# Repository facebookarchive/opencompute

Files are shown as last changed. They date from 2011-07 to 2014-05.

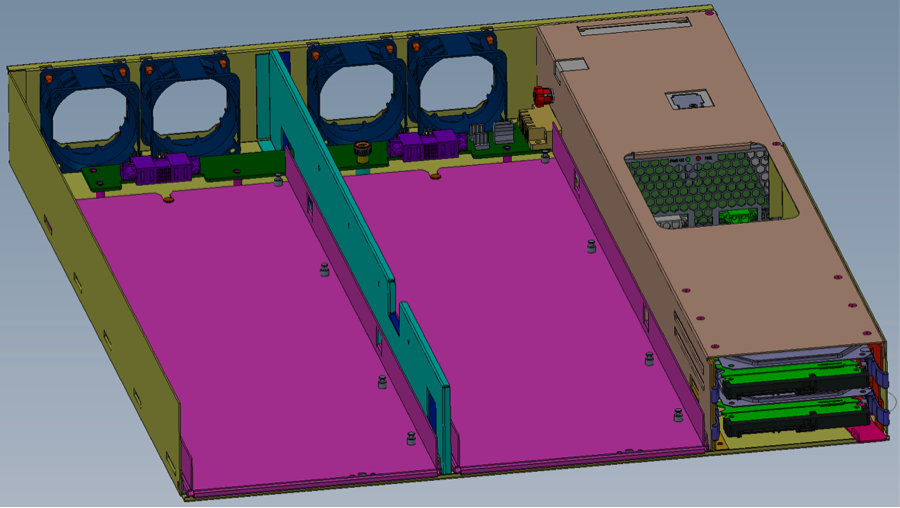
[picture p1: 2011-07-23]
Intel_server_V2/images/ocp_chassis.png

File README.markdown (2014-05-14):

Archived Repo
=============
**This is an archived project: please do not file issues or pull-requests against this repo. All Open Compute specifications are available directly from http://www.opencompute.org/projects/**

# Open Compute Project

Welcome to our beta Git repository. In it you will find specs in multimarkdown for our Intel and AMD V2 motherboard Incubation Projects, as well as a preliminary spec for the Open Rack Incubation Project and a charter for the Open Hardware Management Incubation Project. Mechanical CAD files will be forthcoming. We also have a small project, called Alpha, for converting multimarkdown specs into multi-page pdfs. It is non-functional until the instructions for installing all the latex tools are documented.

One thing to note: the OCP logos for HTML and PDF generation are in /alpha/images. You will need to manually symlink the images in there to a particular project's images folder. The gitmmd2pdf.py script will do this for you, but this script won't generate nice output or compile unless you have all the latex tools installed.

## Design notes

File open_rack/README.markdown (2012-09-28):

This is the Open Rack Incubation project.

Specs and some CAD files are available in the /spec directory. However, the Open Rack 1.0 STEP file can be downloaded from the OCP site at:

http://opencompute.org/wp/wp-content/uploads/2012/09/06-00050_SINGLET_RACK_WITH_BUS_BAR_OPEN_RACK_OCP_REV1_0.rar

You can find the charter in /charter.

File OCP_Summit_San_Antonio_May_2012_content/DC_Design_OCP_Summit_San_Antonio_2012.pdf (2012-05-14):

# Operational Performance and Efficiencies

# Direct Evaporative Cooling/Humidification Systems Comparison

## dan lee, p.e., leed bd+c facebook mechanical engineer, datacenter design

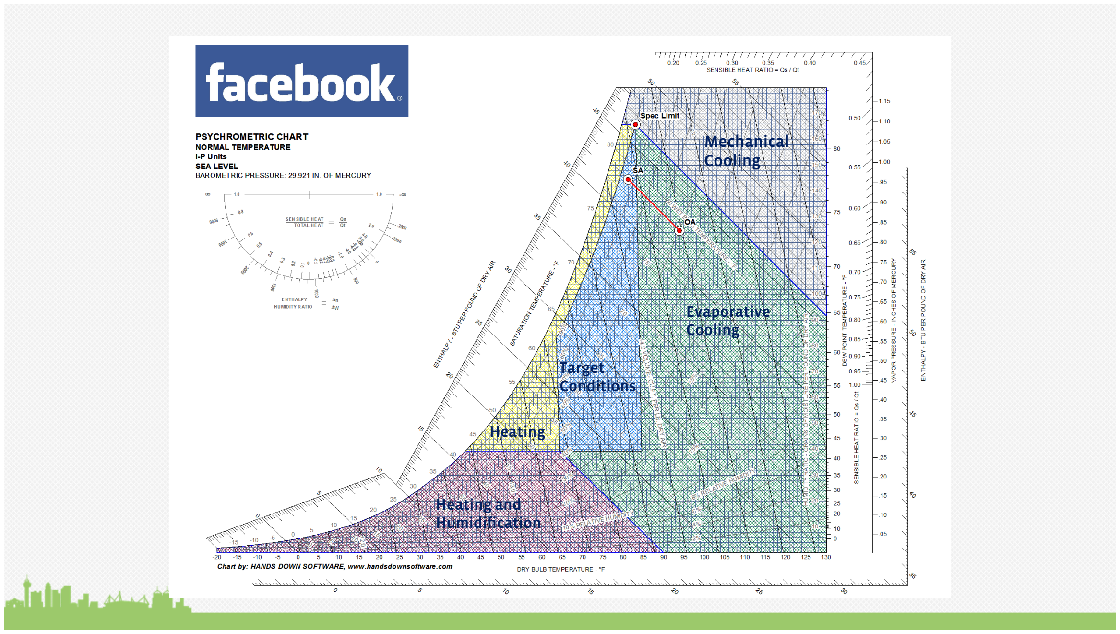
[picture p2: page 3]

Mechanical
Cooling

Evaporative
Cooling

Heating and
Humidification

Heating

Target
Conditions

# Evaporative Cooling

## Scientific Facts: ▪Water evaporates and cools (“free cooling”) ▪Water evaporates on water surface ▪Water evaporation rate is proportional to surface area available

# Atomizing Type Humidifiers

▪Humidifiers break up water into mist, micron sized droplets,

## for rapid moisture absorption ▪There are 2 methods of atomizing water into droplets 1. Pressure Atomizing: High pressure and shear force at humidifier nozzles break water up into a fine mist, used at Facebook 2. Ultrasonic: Ultrasonic vibration breaks water up into a fine mist, not used at Facebook

# Atomizing Type Humidifiers

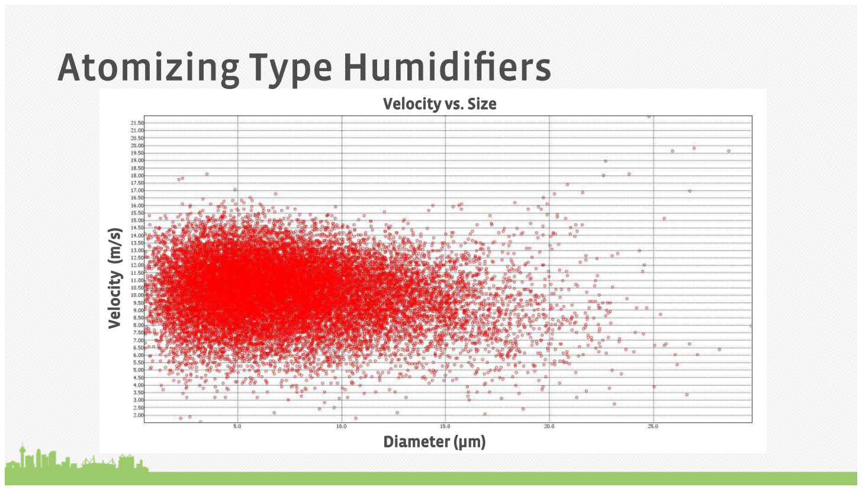
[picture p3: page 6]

Velocity vs. Size

Diameter (µm)

Velocity (m/s)

Misting nozzle with impingement pin

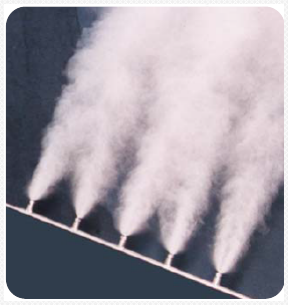
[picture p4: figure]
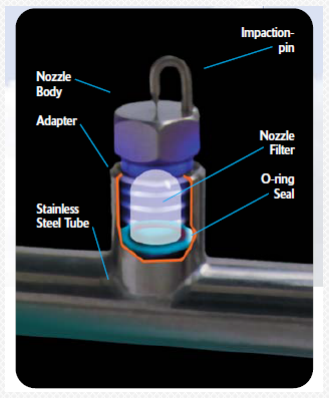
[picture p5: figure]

Misting nozzles with plunger

# Atomizing Type Misting Nozzles

# Typical Misting System Installation

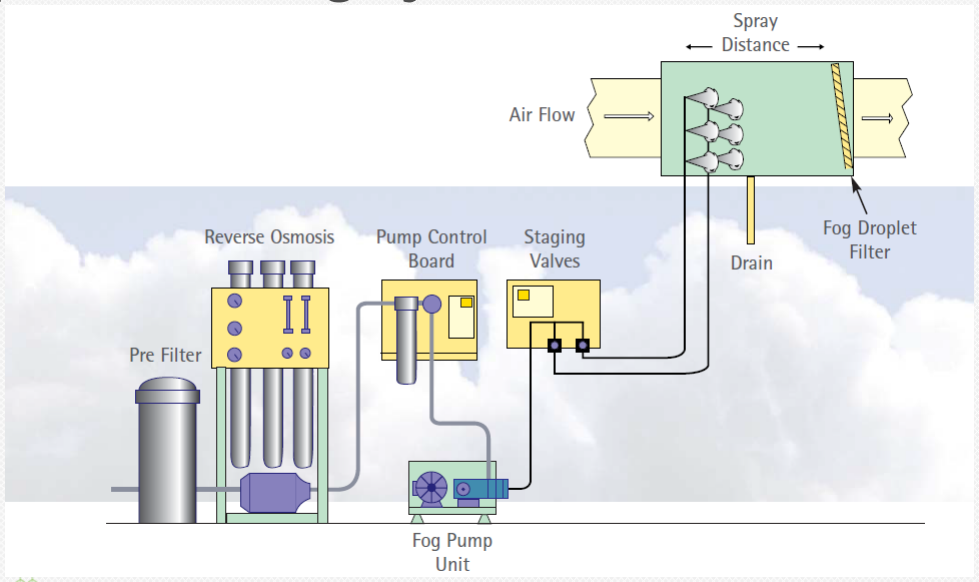
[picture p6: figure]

# Typical Misting Array

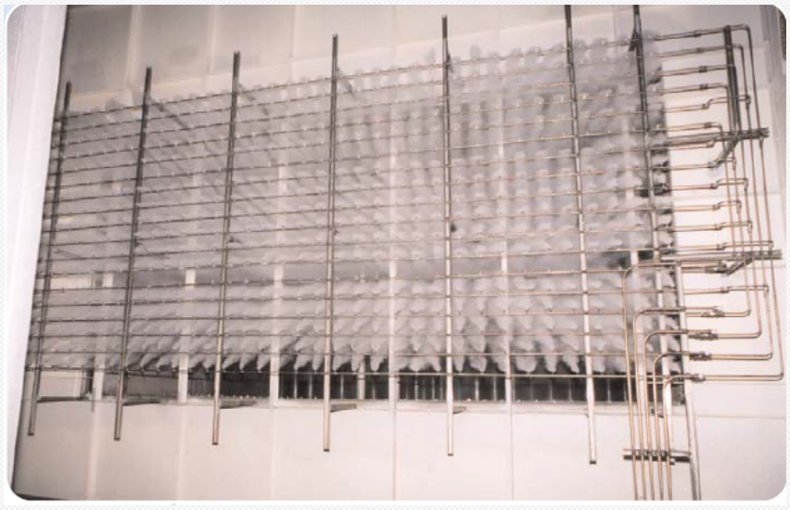
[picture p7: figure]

### - Pros:

1. Good capacity control
2. Not consumable
3. Almost no pressure drop at misting nozzle array

### - Cons:

1. Need RO water => CAPEX/OPEX and foot print for RO Plant
2. RO blow-downs consumes more water than media
3. Types of pressure atomizing heads have impingement pins at the nozzle which need precise tuning to maintain optimal atomizing efficiency. Others have moving parts (plungers/check valves ) in the nozzles that may fail
4. Misting nozzle orifices are very small => Subject to clogging
5. Components on high pressure side (1000psig ) are made of stainless steel => CAPEX
6. Need space to provide the absorption distance
7. Good percentage (15-20%) of water being sprayed drops out of air stream, need mist eliminator and water recycling/polishing system
8. Mist eliminator cause pressure drop in the system => Money to buy and energy to operate

# Atomizing Type Misting Systems

# Typical Media System Installation

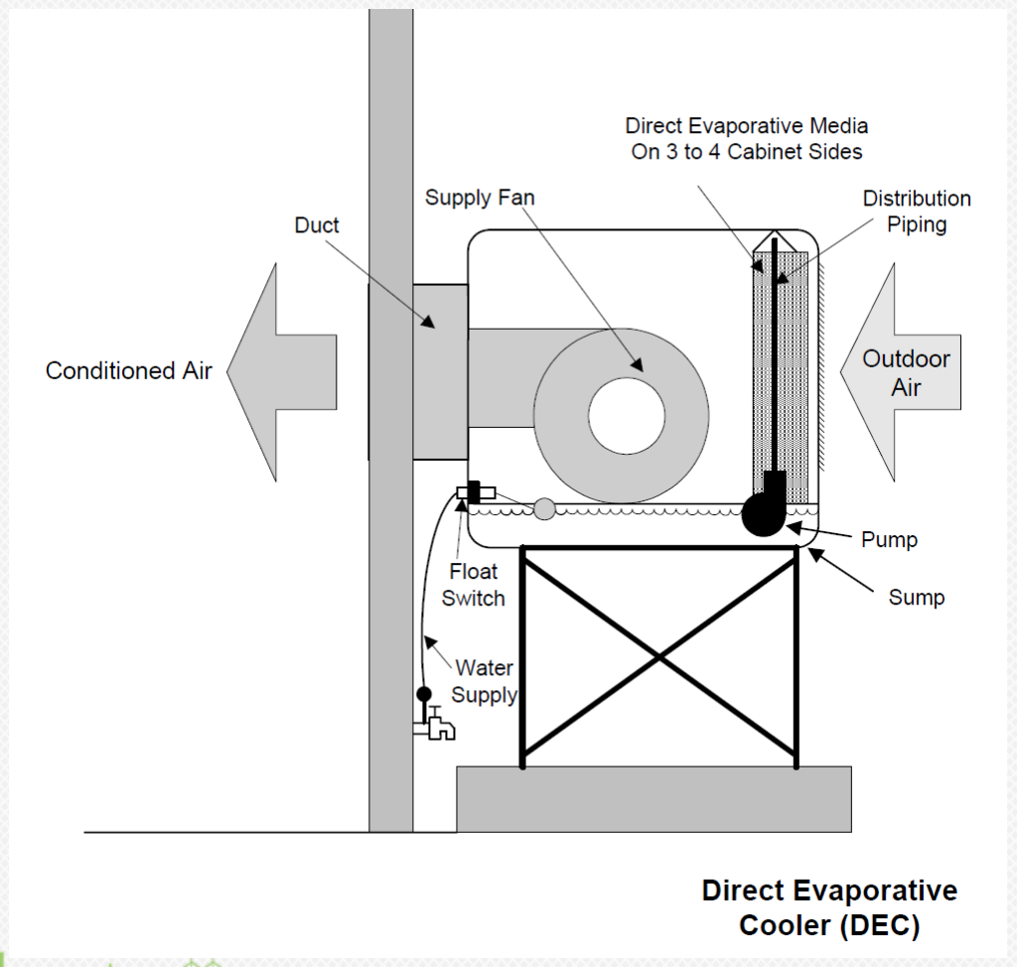
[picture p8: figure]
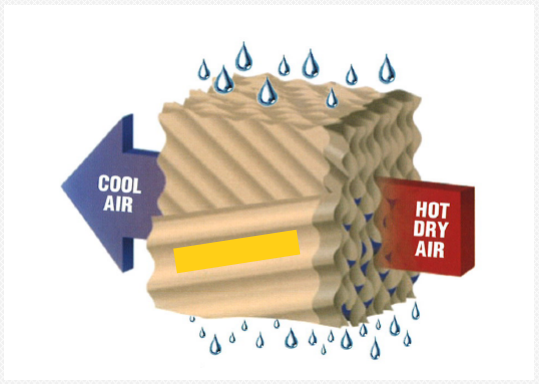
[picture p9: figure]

Fiberglass media in humidifier sections provide extended wet surface for adequate water evaporation to humidify
- Pros:
1. No RO system required => Save cost and foot print for RO system
2. No misting nozzle orifices to potentially clog up
3. No impingement pins to adjust or moving parts in misting nozzles
4. Save space => Absorption distance 8-inches vs. 6-feet
5. System operating pressure is low, no stainless steel components required=> low equipment cost and installation cost
6. Lowest TCO
7. Better Particles removal capability
- Cons:
1. Poor capacity controls: Finite number of steps available
2. System lag: Time to wet ( up cycle ) and time to dry ( down cycle )
3. Media has limited life span, 3-5 years normal use, but could be shorten due to rapid wetting and drying or improper system blow-downs
4. Pressure drop across media

# Direct Evaporative Media Type System

DRY | WET
Velocity (fpm) | Pressure Drop ("WC) | Velocity (fpm) | Pressure Drop ("WC)
3294 | 3.340 | 3311 | 3.340
3055 | 2.920 | 2931 | 2.700
2776 | 2.430 | 2750 | 2.380
2535 | 2.040 | 2479 | 1.950
2129 | 1.450 | 2282 | 1.660
1538 | 0.820 | 2061 | 1.360
1168 | 0.480 | 1822 | 1.050
1002 | 0.400 | 1669 | 0.958
634 | 0.190 | 1281 | 0.609
528 | 0.142 | 733 | 0.202
495 | 0.134 | 538 | 0.152
441 | 0.115 | 507 | 0.135
388 | 0.093 | 462 | 0.115
327 | 0.072 | 417 | 0.103
269 | 0.057 | 356 | 0.082
243 | 0.050 | 299 | 0.064
191 | 0.036 | 276 | 0.056
152 | 0.027 | 221 | 0.040
78 | 0.012 | 119 | 0.017
Mist Eliminator

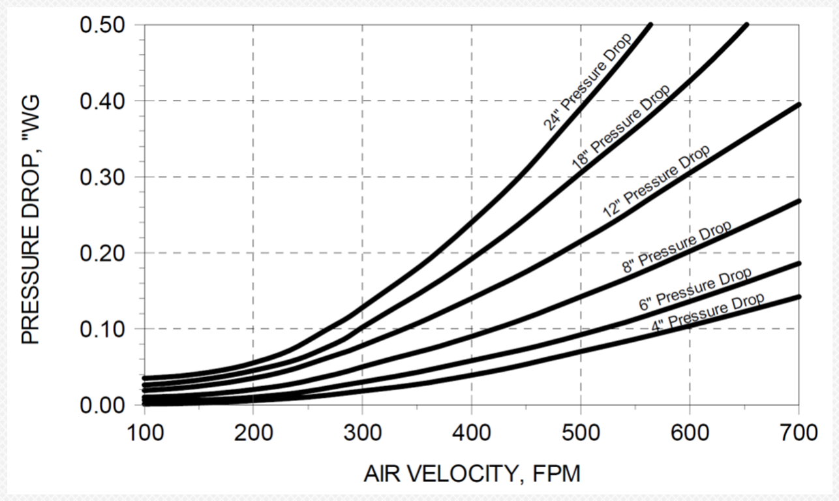
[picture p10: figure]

Direct Evaporative Media

# Air Pressure Drop Comparison

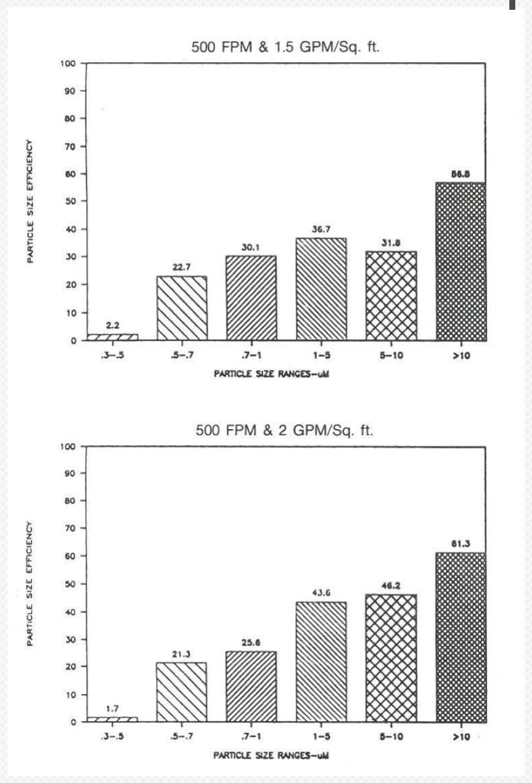
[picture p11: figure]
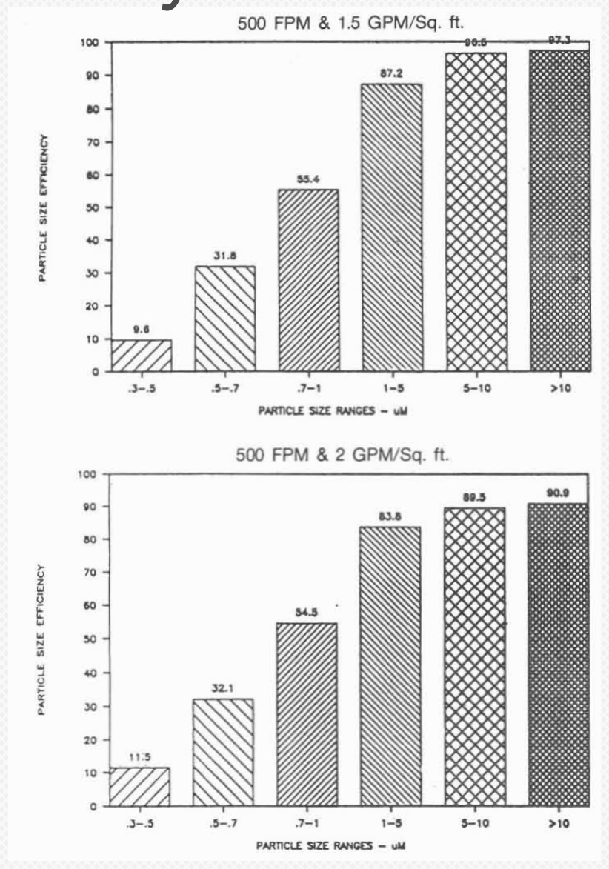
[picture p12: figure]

6” Deep Media | 12” Deep Media

## Particulates Removal Capability of Media System

15

| Misting | Media | Remarks
Reverse Osmosis System | Required | Not required
Reverse Osmosis Plant Space | Required | Not required
Piping material | Stainless | CPVC
Absorption Distance | 6-10ft | 8-12 inches
Misting Nozzle Adjustment | Required | Not required
Misting Nozzles clogging | Yes | No
Capacity Control | Good | Acceptable
Water Consumption | Slightly higher | Slightly lower | RO and Softener blow-down
System Consumable | No | Yes | Media need Replacement
Particles Removal Capability | Less favorable | More Favorable
Pressure Drop | equal | equal | Media vs. Mist eliminator
CAPEX | High | Low | At least a 15% savings
OPEX | Slightly Higher | Slightly lower | RO up-keep vs. Media replacement RO Blow-down vs. Over spraying
Overall | Less Favorable | More Favorable

# Attributes Comparison

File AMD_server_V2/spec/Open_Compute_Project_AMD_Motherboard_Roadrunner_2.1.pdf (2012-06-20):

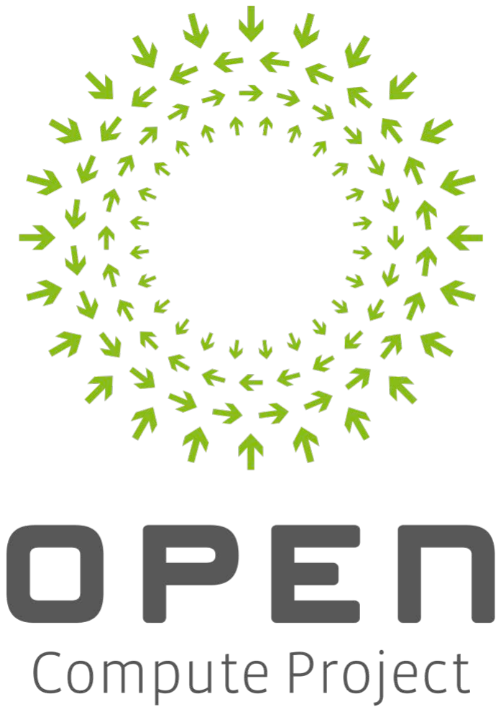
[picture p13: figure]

# AMD Motherboard Hardware v2.1

Authors: Bob Ogrey, Eugene Chung, Otto Joe

2 | April 15, 2012
1 | Revision History
2 | Scope This document defines the technical specifications for the general purpose AMD motherboard that will be used in financial services Open Compute Project servers.
Date | Revision | Description
May 2012 | 1.0 | Initial Release to OCP
June 2012 | 1.1 | Changed Add-in Management Controller Connector, Changed Mezzanine connector, Modified Block Diagram to support BCM5720, Added in EMC and UL safety requirements, added Power Supply Information, Integrated partner feedback

Open Compute Project AMD Motherboard Hardware v2.1

http://opencompute.org | 3
3 | Contents 1 Revision History | 2 2 Scope | 2 3 Contents | 3 4 Overview | 5 4.1 License | 5 4.2 CAD
Models | 6
| 5 Product Descriptions

and

Requirements | 6
| 6 Motherboard
Features | 7
| 6.1 Block

Diagram

for

Base

Design

Implementation | 9
| 6.2 Placement

and

Form

Factor | 9
| 6.3 CPU

and

Memory | 10
| 6.4 Northbridge

PCIe

Usage | 13
| 6.5 Southbridge/Peripheral
Bus Controller | 13
| 7 Leveraged
Design | 13
| 7.1 HPC

Server

in

1U

Chassis | 14
| 7.2 General

Purpose

Motherboard

in

2U

Chassis | 16
| 7.3 Storage

Server Motherboard

in

3U

Chassis | 18
| 8 Chassis Information | 20 8.1 Supported
Configurations | 20
| 8.2 Front

Panel

Switches

and

Indicators | 20
| 8.3 Heat
Sinks | 20
| 9 BIOS | 21 9.1 BIOS
Chip | 21
| 9.2 BIOS
Socket | 21
| 9.3 BIOS

Source

Code | 21
| 9.4 BIOS

Power

Optimization

Features | 21
| 9.5 BIOS

Setup

Menu | 21
| 9.6 Console
Redirect | 22
| 9.7 PXE Boot | 22 9.8 Other
Boot
Options | 22
| 9.9 Remote

BIOS

Update | 22

9.10 Event

Log | 23
10 System
Management | 24
10.1 Requirements | 24
10.2 Management
Port | 25
10.3 Temperature
Sensors | 25
10.4 Fan
Connections | 25
11 Power
System | 25
11.1 Power
Supply | 25
11.2 Power

Connector

Pin-‐out | 26
11.3 Support

for

Open

Compute

Infrastructure | 26
11.4 Power

Budget

for

Open

Platform

Board

Configurations | 27
11.5 VRM
Specifications | 28
11.6 Power
Sequencing | 28
11.7 Power

Optimized

Hardware

Features | 28
12 I/O
System | 29
12.1 PCI-‐Express
Slots | 29
12.2 PCIe

Mezzanine

Card | 29
12.3 IMC

Management

Connector | 30
12.4 Network | 33
12.5 USB
Interfaces | 33
12.6 SATA | 33
12.7 Debug
Header | 33
13 Environmental
Requirements | 34
13.1 Regulatory
Compliance | 34
13.2 Vibration

and

Shock | 34
14 Prescribed
Materials | 35
14.1 Disallowed
Components | 35
14.2 Capacitors

and

Inductors | 35
15 Operating

System

Support | 36
16 Adherence

to

AMD

Motherboard

Design | 36

4 | Overview This document describes the "AMD Financial Services Open Platform and System Solutions," hereafter referred to as the Open Platform board. The AMD Financial Services Open Platform is a G34 motherboard that is optimized for cost and power, and designed to fit into a 1U, 1.5U, 2U, 3U or taller chassis to support different hard drive configurations. The chassis will house this 16" by 16.7" board and come in different U-heights depending on the use case. This system is intended as a low power offering with a feature set tailored to meet the needs of large data center operators and cloud computing service providers. The AMD Financial Services Open Platform is intended to provide a universal, highly re- useable common motherboard that targets 70% to 80% of enterprise infrastructure of Wall Street Council members. Compatibility and deploy-ability are chief design objectives and boards should fit into both the Open Compute/Facebook datacenter infrastructure as well as traditional Enterprise 19" rack enclosures. This means the solution will provide a flexible power delivery system that supports both Facebook Open Compute & Traditional Enterprise Datacenter high-efficiency power supplies. Like previous Open Compute projects, this motherboard is power-optimized and barebones, designed to provide the lowest capital and operating costs. The Open Platform board enables customer driven (versus OEM driven) hardware core features and requirements and will drive an open standards approach that should generate volume and competitive pricing.
4.1 | License As of April 7, 2011, the following persons or entities have made this Specification available under the Open Web Foundation Final Specification Agreement (OWFa 1.0), which is available at http://www.openwebfoundation.org/legal/the-owf-1-0-agreements/owfa-1-0 Facebook, Inc. You can review the signed copies of the Open Web Foundation Agreement Version 1.0 for this Specification at http://opencompute.org/licensing/, which may also include additional parties to those listed above. Your use of this Specification may be subject to other third party rights. THIS SPECIFICATION IS PROVIDED "AS IS." The contributors expressly disclaim any warranties (express, implied, or otherwise), including implied warranties of merchantability, non- infringement, fitness for a particular purpose, or title, related to the Specification. The entire risk as to implementing or otherwise using the Specification is assumed by the Specification implementer and user. IN NO EVENT WILL ANY PARTY BE LIABLE TO ANY OTHER PARTY FOR LOST PROFITS OR ANY FORM OF INDIRECT, SPECIAL, INCIDENTAL, OR CONSEQUENTIAL DAMAGES OF ANY CHARACTER FROM ANY CAUSES OF ACTION OF ANY KIND WITH RESPECT TO THIS SPECIFICATION OR ITS GOVERNING AGREEMENT, WHETHER BASED ON BREACH OF CONTRACT, TORT (INCLUDING NEGLIGENCE), OR OTHERWISE, AND WHETHER OR NOT THE OTHER PARTY HAS BEEN ADVISED OF THE POSSIBILITY OF SUCH DAMAGE. CONTRIBUTORS AND LICENSORS OF THIS DOCUMENT MAY HAVE MENTIONED CERTAIN TECHNOLOGIES THAT ARE MERELY REFERENCED WITHIN THIS DOCUMENT AND NOT LICENSED UNDER THE OWF CLA OR OWFA. THE FOLLOWING IS A NON-EXHAUSTIVE LIST OF MERELY REFERENCED TECHNOLOGY: PCI Express®, Hypertransport™, and USB.

IMPLEMENTATION OF THESE TECHNOLOGIES MAY BE SUBJECT TO THEIR OWN LEGAL TERMS.
4.2 | CAD Models CAD models as fully set forth in this specification are available upon request.
5 | Product Descriptions and Requirements The following section describes the high level features for the various configurations of the Open Platform board. A single board design will be leveraged to meet the three usage cases listed below:
1. HPC server
2. General purpose server for virtualization and standard scale out
3. Storage Platform
| However, in order to optimize for each usage case, a separate board sku with different component selection may be maintained. For example, the general purpose and HPC motherboard will populate only 1 of the 2 tunnel chips for IO expansion. The common motherboard has the following features. It is a 16" x 16.7" board designed to fit into a 1U, 2U, or 3U chassis. The size of the motherboard was increased to support 3DIMMs per channel. It has 2 processors, each with 12 memory sockets, 6 SATA connections per board, on- board 1Gb NIC with integrated management controller, up to four PCIe® expansion slots, mezzanine connector for custom module solutions, two serial port interfaces, and two USB ports. Specific PCIe card support is dependent on usage case and chassis height.
System Configuration | Description (Common motherboard design is used for each of the following system configurations)
HPC | • 1 DIMM per channel (U/RDDR3 1600MHz, 1866 MHz* Stretch Goal) • Fits into the 1U chassis • Cooling and Power for SE 140W parts • 1 SR5670 tunnel • Supports 6 SATA drives natively off of the "Southbridge" • Supports up to ten 2.5" total drives with add-in card (Full details in section 7.2) • Supports up to 2 low-profile PCIe cards or 1 standard height card • Single 1Gb on-board controller via BCM5725 • 10Gb solution via add-in mezzanine card
General Purpose | • 3 DIMM per channel (Up to 1600 MHz support) • Fits into 2U chassis • Cooling and Power for SE 140W Parts

| • Support for twenty five 2.5" SATA/SAS drives • Supports up to 1 standard-height and 1 low-profile PCIe cards (2 cards total) • Single 1Gb on-board controller via BCM5725 • 10Gb solution via add-in mezzanine card
Storage | • 3 DIMM per channel (Up to 1600 MHz support) • Fits into 3U chassis • Cooling and Power for SE 140W Parts • Support for thirty five 2.5" SATA /SAS drives • Supports up to 4 full-height, short PCIe cards • 10Gb solution via add-in mezzanine card
6 | Motherboard Features The base motherboard design supports the following feature set and will have different stuff options and implementations depending on the use case. A general description of the base motherboard design is documented below.
Component | Function
Socket | Socket G34
Processor | • Two sockets per board • Support for AMD processor codenamed "Magny-Cours", "Interlagos", and "Abu Dhabi" processors • Abu Dhabi ("Orochi"-Rev C) support is mandatory • Supports Infrastructure Group A, B, C: 85W, 115W, and 140W TDPs • Magny-Cours: 8/12 cores codenamed "Greyhound" for Hydra die (MCM) • Interlagos: 12/16 cores codenamed "Bulldozer" for Orochi die (MCM) • Abu Dhabi: 4/8/12/16 cores codenamed "Piledriver" (MCM) • Coherent Links: Triple x16 HyperTransport3 link supporting speeds up to 6.4 GT/s with support for HT1 operation @ 2.0 GT/s
Memory | • HPC config: 1 DIMM’s per channel per processor (total of 4 DIMMs per processor and 8 DIMMs per system) • Support up to 1866 MHz for 1 DIMM per channel • General Purpose config: 3 DIMM’s per channel per processor (total of 12 DIMMs per processor and 24 DIMMs per system) • Three RDIMMs/channel up to 1600 MT/s • 1DIMM/channel = 1600 MHz support • 2DIMM/channel = 1333 MHz support • 3DIMM/channel = 1066 MHz support • Supports DDR3 1.5V, DDR3L (1.35V), DDR3U (1.25 V) • Targeted configuration is 96 GB, 1.35V, RDDR3, 1333 MHz • Future LRDIMM (Load Reduced DIMM) support with AMD

| processor codenamed "Orochi" required • UDIMM support
I/O | • Two Tunnel SR56X0 Chipsets • Single SR5670 for HPC and General Purpose Server • One SR5670 and one SR5690 for Storage server • Interconnect via ncHT3 16x16 link to North-Bridge. ncHT1 operation will not be supported with Orochi based products. • MD SP5100 South Bridge • onboard SATA 2.0 ports. • 2 serial port • 2 USB port interfaces. 1 via the debug header, 1 via the DP9 connector.
Drive Bays | Support for 2.5" and 3.5" drives. Number of drives dependent on configuration, use case, and ODM implementation.
Video | No embedded support.
I/O Slots | • Up to 4 PCI Express® slots • Motherboard can support up to two x8 PCIe slots and two x16 PCIe slots (4 total) • Three x8 PCIe slot support in a 1U or 2U chassis
Networking | • Embedded BCM5725. 10GB via add-in mezzanine. • Population Option for BCM 5720. (No-popped once the BCM 5725 reaches production)
System Management | • Integrated Management Controller via BCM5725. • KVM support via add-in management card
System fans | Non-redundant and non-hot-swap, support cooling for Infrastructure Group A processors.
Board Dimensions | 16" x 16.7"
Expected Layer Count | 12 – 14 layers
Power target per MB | See Chapter 10.

### 6.1 Block Diagram for Base Design Implementation

Figure 1 illustrates the functional block diagram for the storage node version of the
| Open Platform board.

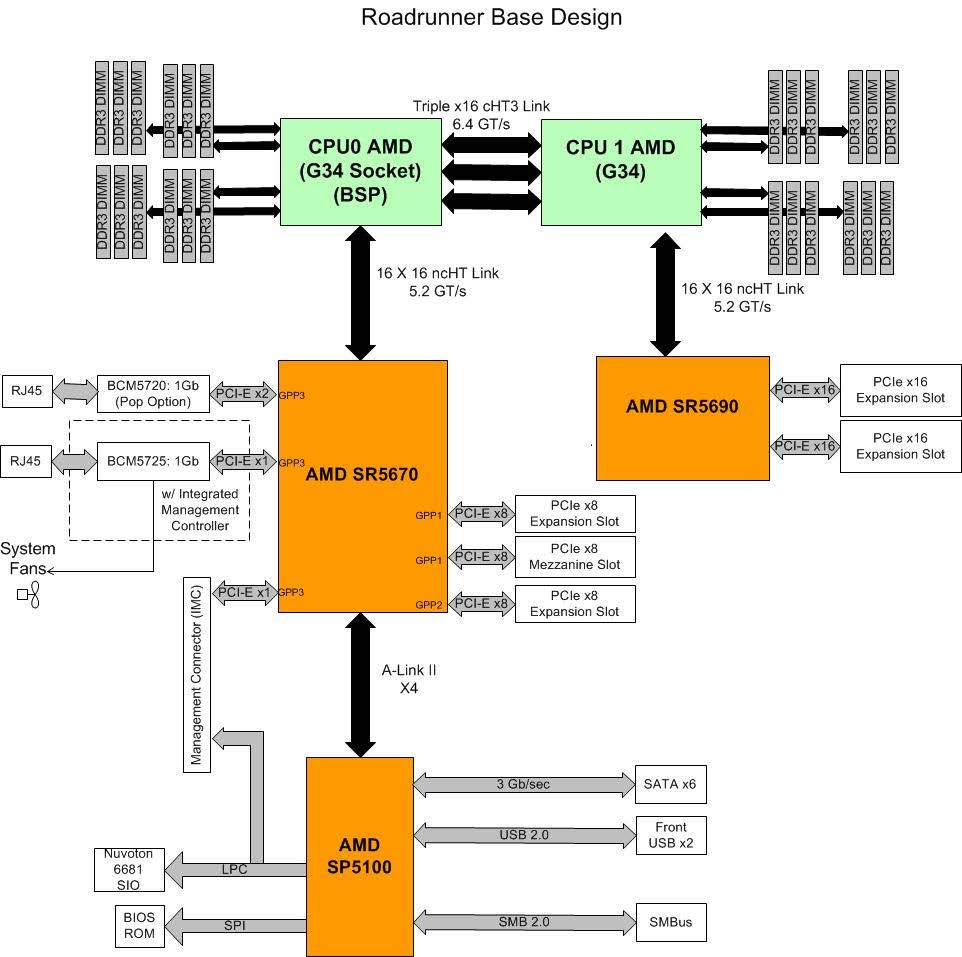
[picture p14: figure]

Figure 1 Functional Block Diagram
6.2 Placement and Form Factor The motherboard's form factor is 16 x 16.7 inches with cutouts to support dual power supply locations. Figure 2 illustrates board placement. The placement shows the relative positions of key components, while exact dimension and position information will be determined in the future. Once released, the ODM should strictly follow the form factor, PCIe slot position, front IO port positions, PCIe mezzanine card connector position, power connector, and mounting holes, while other components can be shifted based on layout routing as long as relative position is maintained. Each specific configuration (HPC, general server, or storage) will use a slightly different flavor of the Open Platform board and chassis as shown in section 7.2.

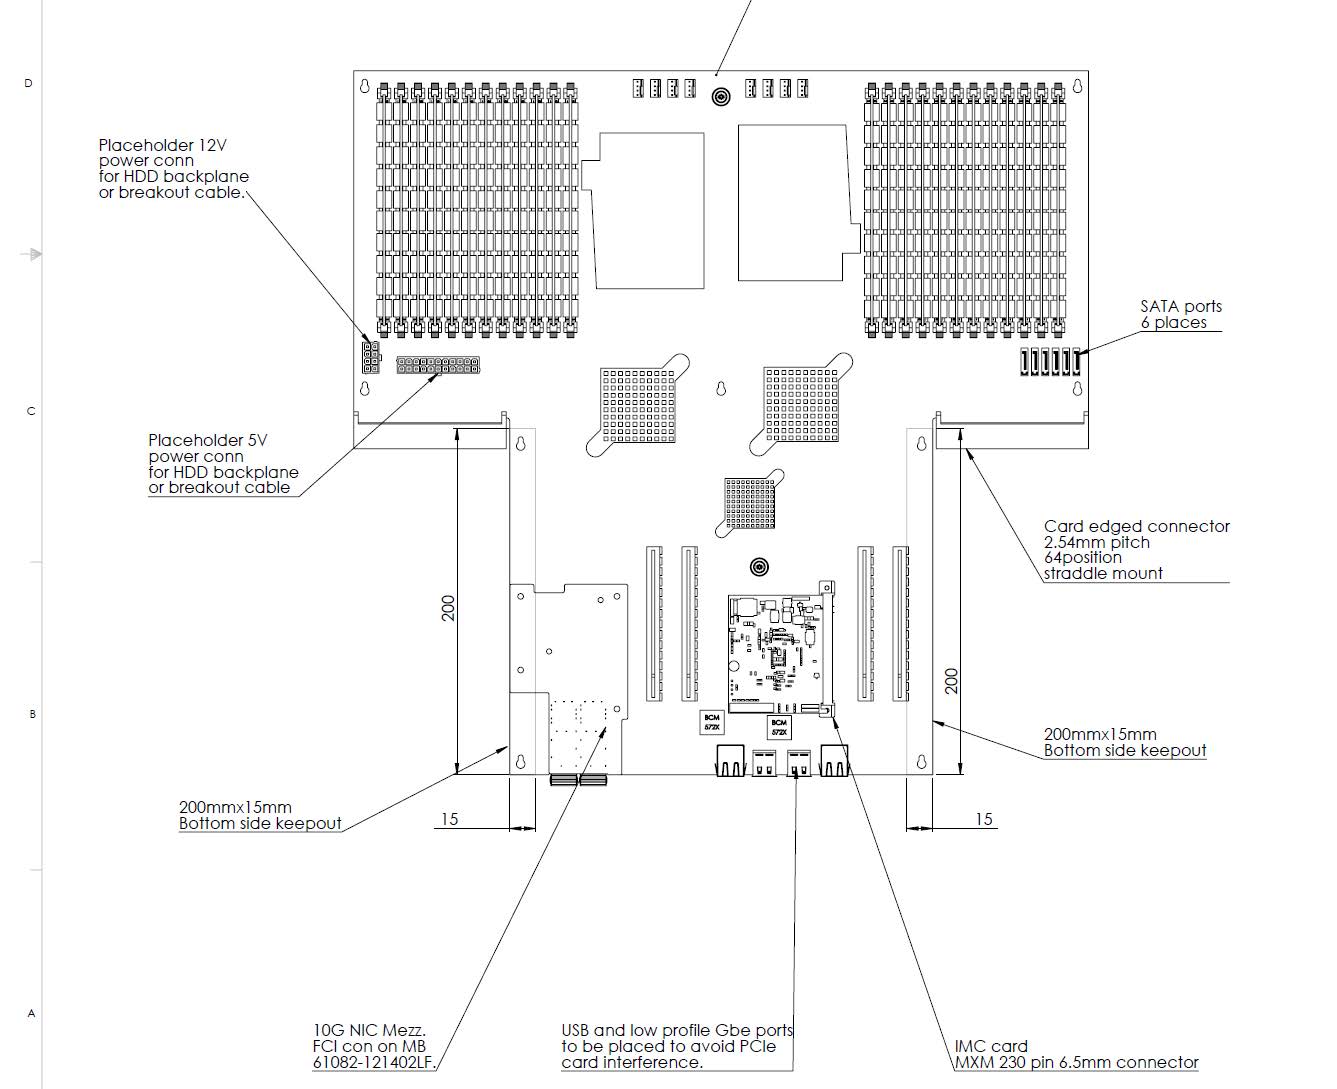
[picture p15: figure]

Figure 2 AMD Motherboard Component Placement
6.3 CPU and Memory The Socket G34 processor supports multi-chip modules (MCMs). The MCMs use HyperTransport™ technology as the inter-processor link. Figure 1 illustrates the internal HT link connections between the dies and the package. Magny-Cours (6100 Series) uses the Greyhound core while Interlagos (6200 Series) uses the Bulldozer core. Abu-Dhabi is based on the Piledriver core will be available Q2 2012 and offers drop-in compatible part with 200 MHz performance uplift. The Open Platform board should be designed to accommodate all three G34 power bands—85W, 115W, and 140 Interlagos and Abu Dhabi parts. The SE Abu Dhabi will consume up to 125A on the core and 25A on the north bridge. The board must support a 165A IDD spike and a 125A Load step on the core rail. Interlagos in the G34 package has the following characteristic:

- 32 nm AMD Family 15h processor
- 16, 12 or 8 CPU cores - Each pair of cores comprises a "Bulldozer" module, a.k.a Compute Unit
- Each individual core has its own 16-Kbyte L1 data cache
- Each Bulldozer module has a single 64-Kbyte L1 instruction cache
- 2MB L2 cache per Bulldozer module
- Quad-channel U/RDDR-3 memory (also supports low voltage DDR3)
- Four HyperTransport™ technology links supporting speeds up to 6.4 GT/s.
- AMD-Virtualization™ (AMD-V™) technology with Rapid
- AMD Turbo CORE technology

6.3.1 DDR3
It is a requirement to support both 1.5V, 1.35 V and 1.25V memory offerings. This requires SPD detection by the system bios to detect the correct memory voltages and hardware interfaces to program the VDDIO voltage rail based on the populated memory configuration.
Future LR-DIMM support is a requirement and can be implemented with no adverse effects to standard DDR3 operation by following the chip select routing details. This involves routing the MA3_CS_L[1:0] to all DDR3 DIMM sockets in parallel.
Surface mount DIMM connectors are recommended for this design.
4 channels DDR3 registered memory interface on each CPU:
- 3 DDR3 slots per channel per processor (total of 24 DIMMs on the motherboard)
- RDIMM/LV-RDIMM (1.5V/1.35V/1.25V), LRDIMM, and UDIMM/LV-UDIMM (1.35V/1.25V)
- SR, DR, and QR DIMMs
- DDR3 speeds of 800/1066/1333/1600/1866
- Up to maximum 768GB memory with 32GB RDIMMs

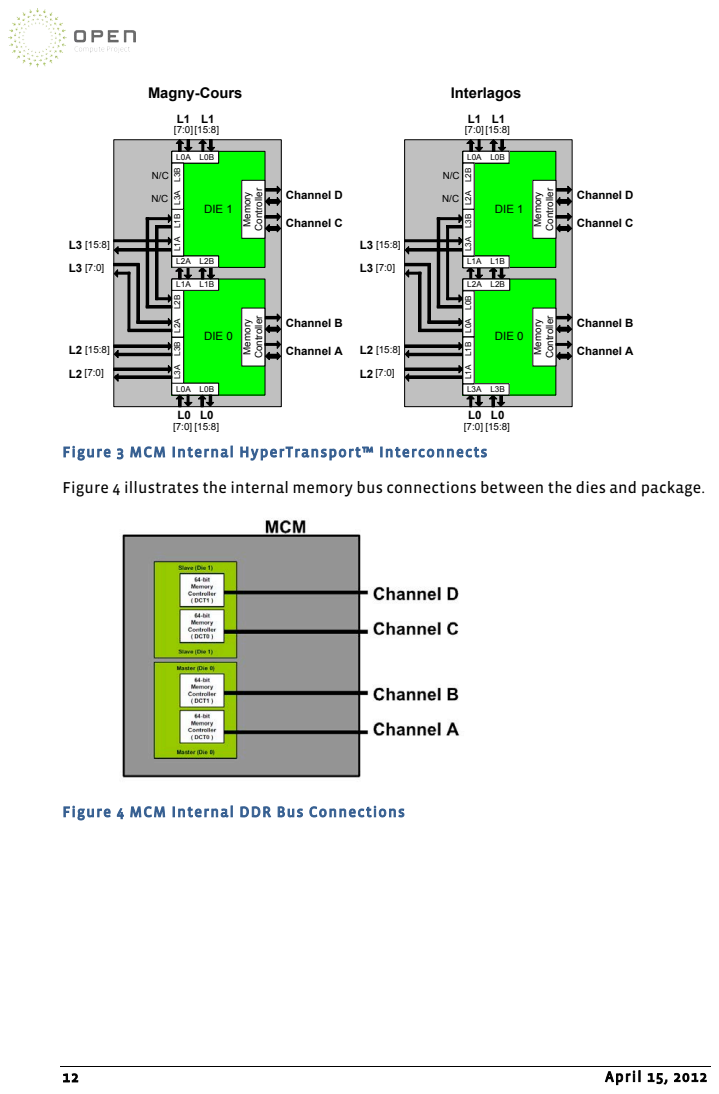
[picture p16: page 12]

Figure 3 MCM Internal HyperTransport™ Interconnects

Figure 4 illustrates the internal memory bus connections between the dies and package.

Figure 4 MCM Internal DDR Bus Connections

6.4 | Northbridge PCIe Usage The motherboard supports two SR5690 chipsets to provide maximum I/O in a balanced configuration. There are three different versions of the tunnel chipset, each with a different PCI-Express port configuration that is documented below.
| GPP1 Port | GPP2 Port | GPP3 Port | Total Available Lanes
SR5650 | 16 lanes | 0 lanes | 6 lanes | 22 lanes
SR5670 | 16 lanes | 8 lanes | 6 lanes | 30 lanes
SR5690 | 16 lanes | 16 lanes | 6 lanes | 42 lanes

Depending on the usage case, the board will have different chipset population options. Please refer to section 6.0 for further details. For the storage configuration, a 5650 and a 5690 will be populated on the motherboard.
6.5 | Southbridge/Peripheral Bus Controller The motherboard uses the AMD SP5100 Southbridge chipset, which supports the following features: • 2 USB 2.0 ports (on the front panel) • SATAII ports • SPI interface • SMBUS interface (master and slave)
7 | Leveraged Design The motherboard has been designed to be easily leveraged to support the HPC, general purpose, and storage configurations. All of the three use cases will be built around the same core design, but a few changes in both component population and the PCB will be made to optimize the design for the given application. The Base Model PCB will support two tunnel chips and 3DIMM per channel. Changes for the other configurations are listed below.
Segment | PCB | Component Change
HPC | Some memory traces are removed from the base model to support fastest possible 1DIMM per channel implementation. | Second I/O tunnel (56X0) is not populated.
General Purpose | Base Model PCB | Second I/O tunnel (56X0) is not populated.
Storage | Base Model PCB | SR5690 is populated to support two additional x16 PCIe slots. A SR5650 (in lieu of the 5690) can be populated if x8 support is sufficient.

### 7.1 HPC Server in 1U Chassis

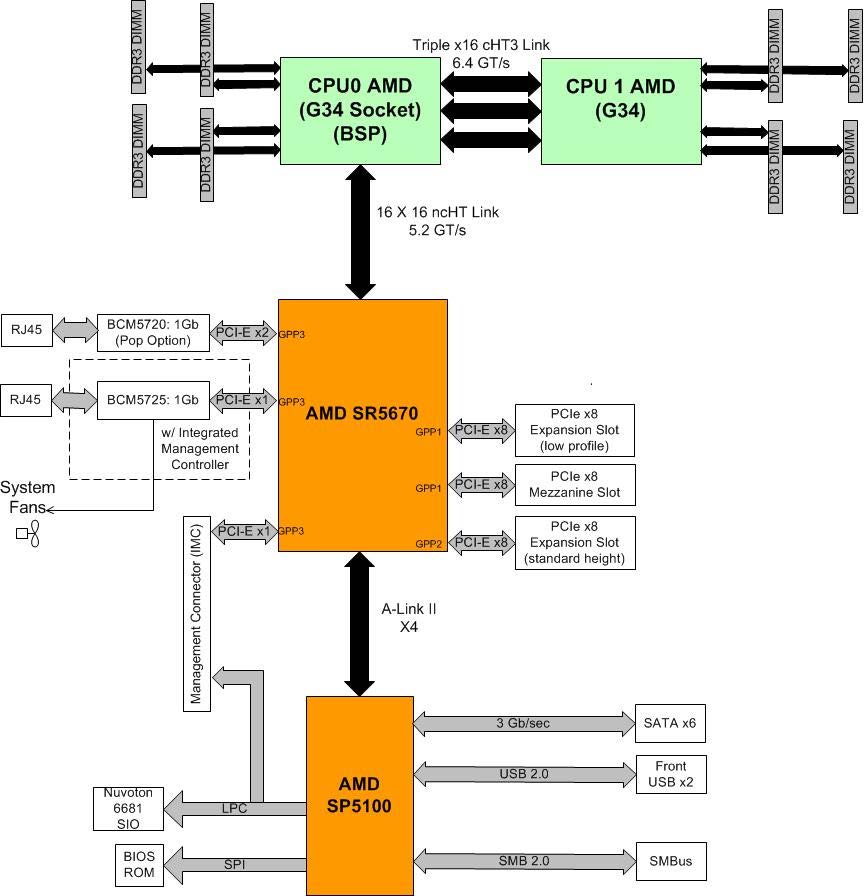
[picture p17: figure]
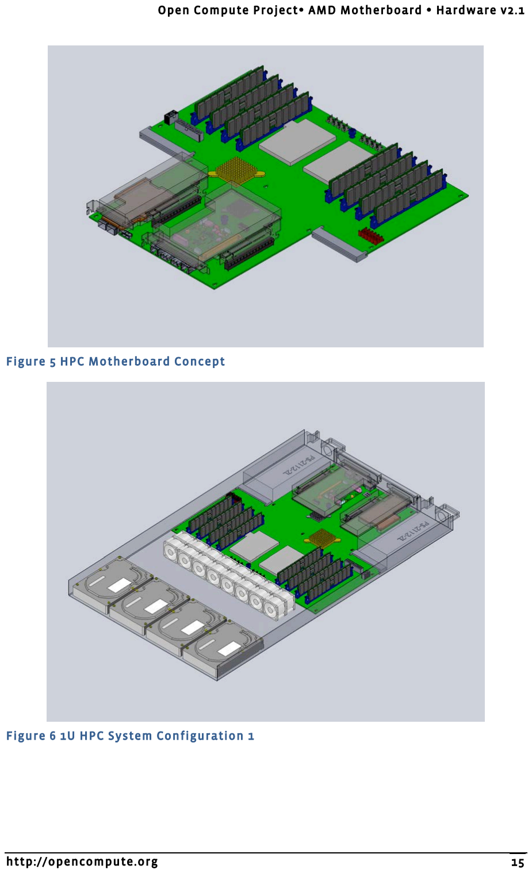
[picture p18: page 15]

Figure 5 HPC Motherboard Concept

Figure 6 1U HPC System Configuration 1

### 7.2 General Purpose Motherboard in 2U Chassis

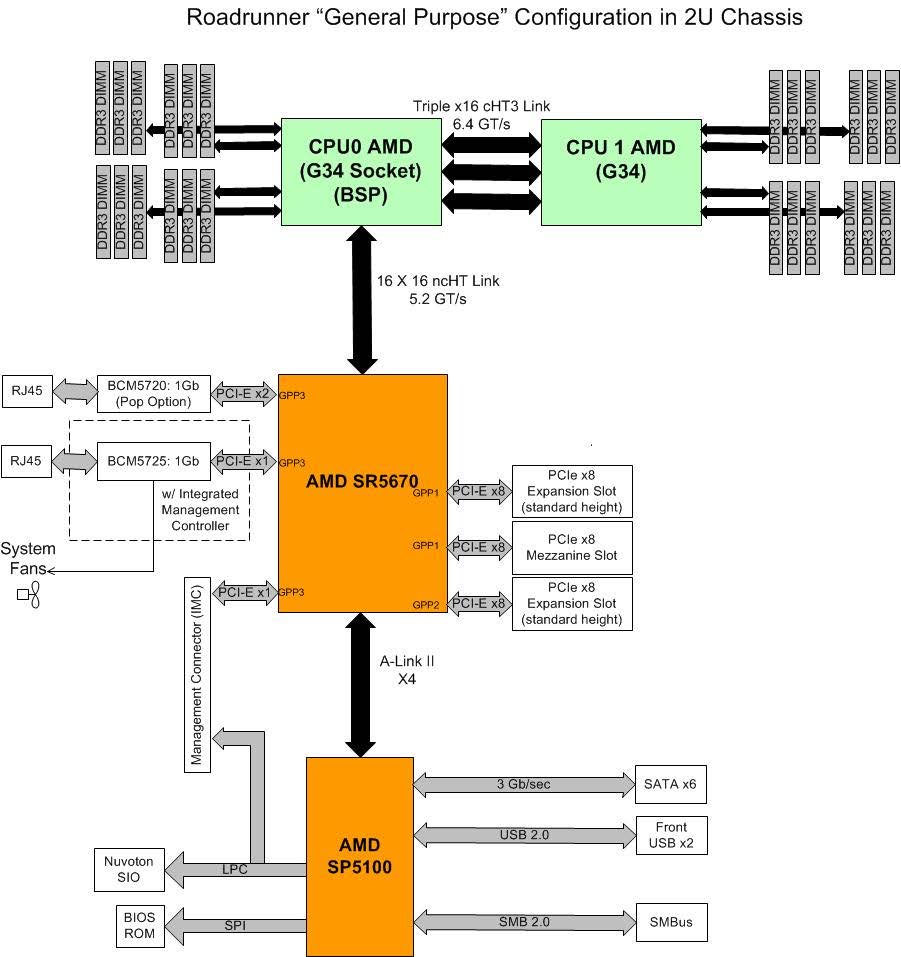
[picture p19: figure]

Figure 7 Roadrunner General Purpose Configuration in 2U Chassis

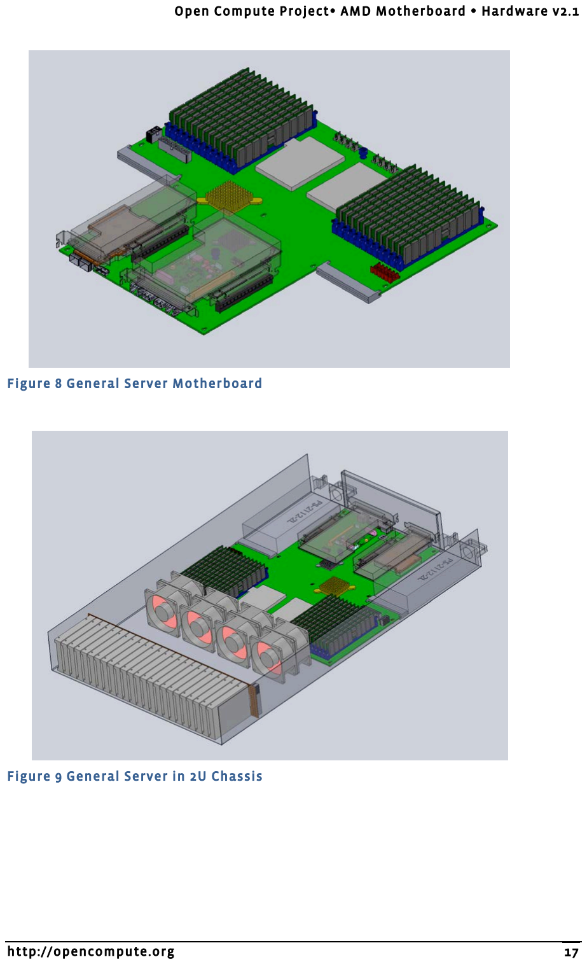
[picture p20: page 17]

Figure 8 General Server Motherboard

Figure 9 General Server in 2U Chassis

### 7.3 Storage Server Motherboard in 3U Chassis

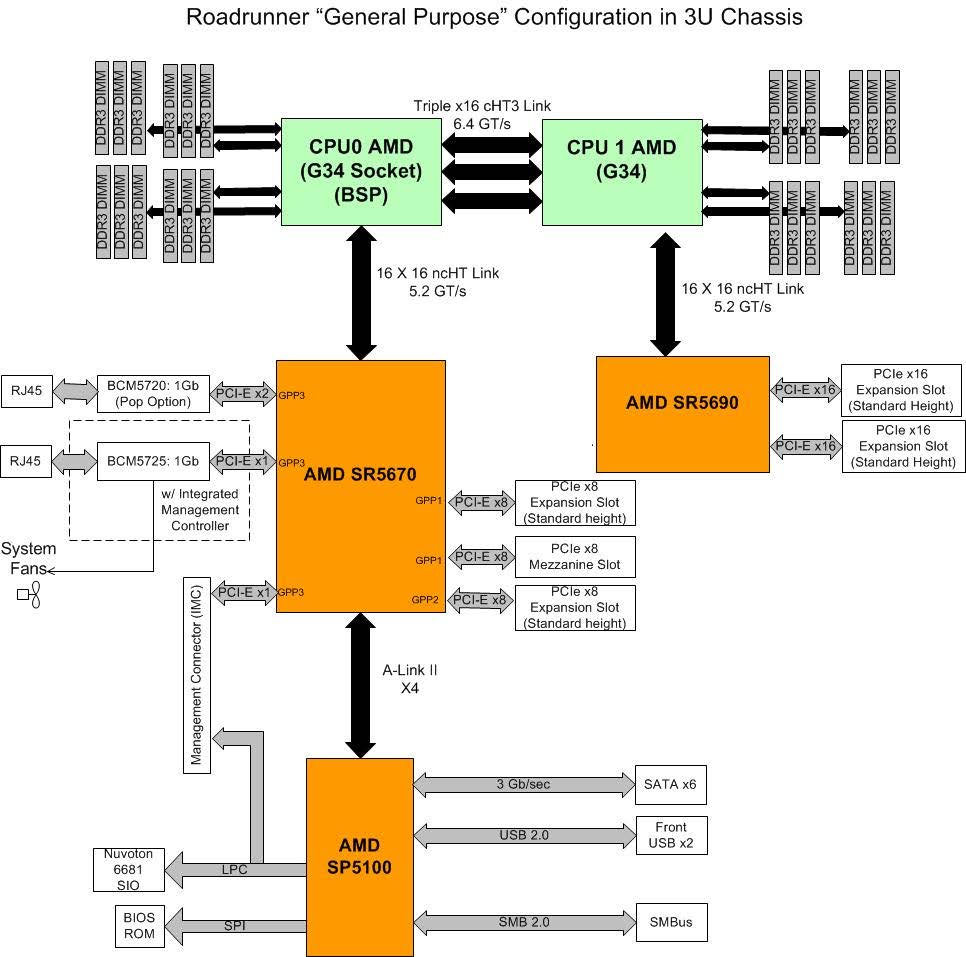
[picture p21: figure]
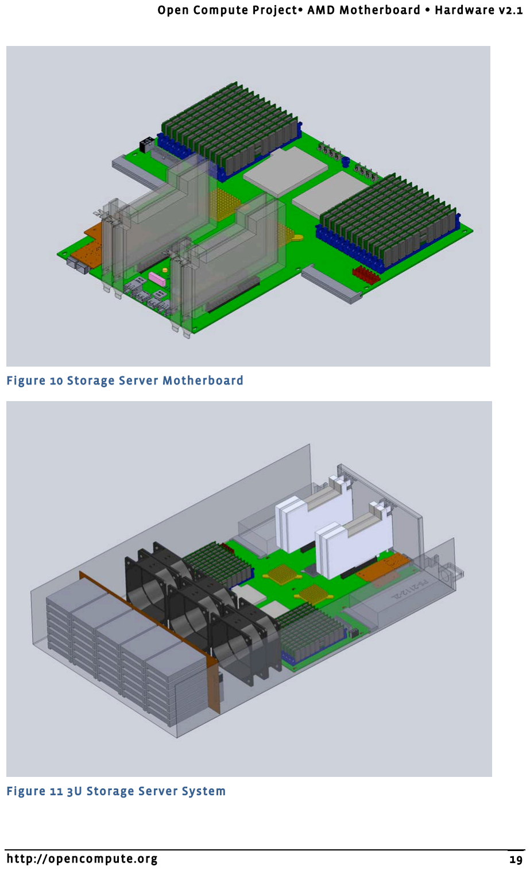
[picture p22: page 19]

Figure 10 Storage Server Motherboard

Figure 11 3U Storage Server System

8 | Chassis Information The Open Platform board motherboard platform is designed to fit in a custom 1U/1.5U/2U/3U chassis. The Open Platform board can fit into an Open Rack compliant chassis that will need to be developed. It can fit into future Open Compute1.0 chassis that have been designed with multiple holes punched into the base. However, it cannot fit into currently deployed Open Compute chassis because of incompatible hole patterns. The 1U chassis is 730mm x 438.3mm x 43.6 mm and must be compatible with standard 19" EIA rack configurations. The chassis is designed so that it can be easily assembled and the major components of the system are readily accessible.
8.1 | Supported Configurations The chassis will be available in several different heights but will maintain the same drive cage support mounting for the various U-heights. A suggested support matrix is shown below. However, the ODM may choose to provide alternate drive cage solutions based on their existing solutions.

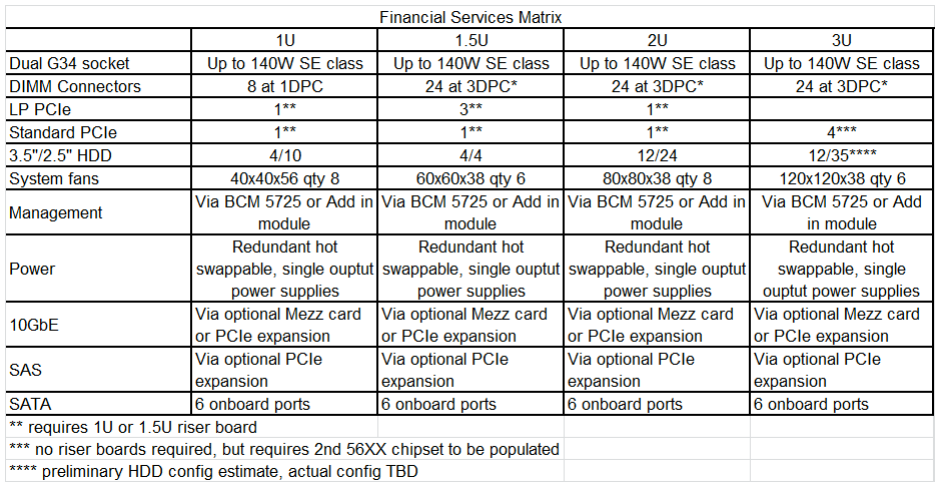
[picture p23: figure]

8.2 | Front Panel Switches and Indicators TBD
8.3 | Heat Sinks The motherboard supports heat sinks that are mounted according to the AMD G34 heat sink specification. The mounting device employs a back-plate and receptacles for screw- down type heat sinks. The ODM must comply with all keep out zones defined by AMD.

9 | BIOS The ODM is responsible for supplying and customizing a BIOS for the motherboard. The specific BIOS requirements are outlined in this section.
9.1 | BIOS Chip The BIOS uses the SP5100's SPI interface. The ODM is responsible for selecting a specific BIOS chip that meets the required functionality.
9.2 | BIOS Socket A socket on the motherboard holds the BIOS chip, which allows for manual replacement of the BIOS chip. The BIOS socket is easily accessible; other components on the motherboard do not interfere with the insertion or removal of the BIOS chip.
9.3 | BIOS Source Code The BIOS source code comes from AMI or Phoenix. The ODM is responsible for maintaining the BIOS source code to make sure it has latest code release from AMI or Phoenix and AMD.
9.4 | BIOS Power Optimization Features The BIOS is tuned to minimize system power consumption and should expose all device configuration, device feature, and power saving options in BIOS, to provide maximum flexibility to tune the system to the workload and operational environment. It should enable the following features: • Unused devices disabled, including PCIe lanes, PCI, USB ports, and SATA/SAS ports • Tuning CPU/chipset settings to reach minimized power consumption and best performance • SPECpower is used as guidance for ODM to validate BIOS tuning results Best practices include the following: • Full C1E support. • "Efficient single fan variant" system fans that are non-redundant and utilize an aggressive fan management algorithm • Disable HT Assist (Probe Filter Option) • BIOS F2 setting(s) for HT Link Frequency. Enable cHT1 operation by default • BIOS F2 setting(s) for HT link width. Enable 8-bit coherent link by default. • Bios option to disable IOMMU operation • Bios disable option for the BCM5275 NIC ports. ’ • PSI options enabled by default • Power Save options enabled • A "green button" bios option to load all power optimized features • Bios should enable CC6 (per core power gating) features in the processor. No specific HW changes need to be made to support this feature.
9.5 | BIOS Setup Menu The ODM must provide a BIOS specification, which includes the complete BIOS, setup menu, and default settings. The setup menu allows its options to be configured before

the operating system loads. The configuration options available through the boot menu include the following:
- Setting for power feature after AC failure; default is set to keep last state.
- Setting for console redirection. Selectable options to support select console redirection from local COM port or the BMC's virtual UART for SOL.
- Setting for altitude of server deployment location.
- Hardware health monitoring display.
- Setting for watchdog timer; default is enabled and timeout value is 15 minutes.
- Event log viewing and clearing.
- Setting for ECC error threshold, available settings are 1, 4, 10, and 1000.
- Display power on self test (POST) results during boot up.
- If a CMOS checksum error happens (for example, caused by a BIOS update), the BIOS loads the system default automatically after showing a text message in the console for 5 seconds and rebooting the system to apply the update without user input.
- Setting to disable all "wait for keyboard input to continue" features.
9.6 | Console Redirect The BIOS detects the presence of a video card in a PCIe slot. If a video card is present, the BIOS directs its output to the video card. If no video card is present, the BIOS directs its output to the board-mounted RS-232 console output.
9.7 | PXE Boot The BIOS supports PXE boot. When PXE booting, the system first attempts to PXE boot from the first Ethernet interface (eth0). If a PXE boot on the first Ethernet interface fails, the BIOS attempts to PXE boot from the second Ethernet interface (eth1).
9.8 | Other Boot Options The BIOS also supports booting from SATA/SAS and USB interfaces. The BIOS provides the capability to select boot options.
9.9 | Remote BIOS Update The BIOS can be updated remotely under these scenarios: • Scenario 1: Sample/Audit BIOS settings • Return current BIOS settings, or • Save/export BIOS settings in a human-readable form that can be restored/imported (as in scenario 2) • Scenario 2: Update BIOS with pre-configured set of BIOS settings • Update/change multiple BIOS settings • Reboot • Scenario 3: BIOS/firmware update with a new revision • Load new BIOS/firmware on machine and update, retaining current BIOS settings

- Reboot
Additionally, the update tool(s) should have the following capabilities:
- Update from the operating system over the LAN – the OS standard is CentOS v5.2
- Can complete update with a single reboot (no PXE boot, no multiple reboots)
- BIOS update or BIOS setup option change take no more than 5 minutes to complete
- No user interaction (like prompts)
- Can be scripted and propagated to multiple machines

### 9.10 Event Log

The BIOS logs system events through the baseboard management controller (BMC).

9.10.1 Logged Errors
- CPU/memory errors: Both correctable ECC and uncorrectable ECC errors should be logged into event log. Error categories include DRAM, HyperTransport Link, and L3 Cache.
- HyperTransport errors: Any errors that have a status register should be logged into the event log. Fatal or non-fatal classification follows the chipset vendor's recommendation.
- Internal parity errors: All errors which have status register should be logged into the event log. Fatal, non-fatal, or correctable classification follows the chipset vendor's recommendation.
- PCIe errors: All errors which have status register should be logged into Event Log, including root complex, endpoint device and any switch upstream/downstream ports if available. Link disable on errors should also be logged. Fatal, non-fatal, or correctable classification follows the chipset vendor's recommendation.
- POST errors: All POST errors detected by the BIOS during POST should be logged into the event log.
- Power errors:
- MHOT and PROCHOT errors: MEMHOT events should be logged with event source information indicating whether the event was triggered by a DIMM or a DIMM's Voltage Regulator. PROCHOT events should be logged with event source information indicating whether the event was triggered by a CPU or the CPU's Voltage Regulator.

9.10.2 Error Threshold Settings
An error threshold setting must be enabled for both correctable and uncorrectable errors. Once the programmed threshold is reached, an event should be triggered and logged.
- Memory Correctable ECC: The threshold value is 1000. When the threshold is reached, the BIOS should log the event including DIMM location information and output DIMM location code through the Facebook debug card.
- HyperTransport errors: Follow the chipset vendor's suggestion.
- PCIe errors: Follow the chipset vendor's suggestion.

10 System Management The following sections describe the system management features implemented on the Open Platform board platform.

### 10.1 Requirements

| • Out-of-band Management is provided by the integrated BMC (baseboard management controller) in the BCM5725 NIC. • A separate NCT6681D eSIO/Hardware Monitor assists the BMC to provide fan speed control and fan/temperature monitoring. • The integrated BMC provides out-of-band remote management access and control via: 1) the GbE network port in the BCM5725 or via a standard NC-SI interface that can be connected to a separate discrete NIC. • The integrated BMC provides an IPMI/DCMI event log. BIOS will store memory or boot errors in the event log. The BMC will store sensor threshold events in the event log. The event log can be read in-band or out-of- band using IPMI/DCMI standard interfaces. • The BMC provides the following out-of-band remote control features: • Support for IPMI and DCMI network interfaces • Power-on/off and hard reset power control (via IPMI/DCMI or SMASH- 2.0/WSManagement protocols) • Serial text console redirect (via IPMI SOL protocol, telnet, or SSH protocols) • IPMI Event log (via IPMI/DCMI) • Temperature sensors and hardware inventory (via IPMI/DCMI) • The BMC provides the following in-band interfaces for systems management agents running on the host operating system or BIOS • KCS host HW/SW interface compliant w/ DCMI and IPMI • IPMI Event log rd/wr (via IPMI/DCMI commands) • Sensor and temperature monitoring (via IPMI/DCMI commands) • BMC Configuration (via IPMI/DCMI commands) • The BMC also provides the following advanced management features: • Power capping per DCMI specification • Boot to a remote network CD image • Active Directory Authentication via Kerberos for SMASH 2.0/WSManagement and SSH console redirect out-of-band protocols • Web browser GUI for basic management functions Notes: • DCMI (Data Center Management Interface) is a standard targeted for Data Center management. It uses interfaces defined in IPMI as the underlying protocol. DCMI minimizes the number of optional interfaces, requires support for specific temperature sensors, and adds power capping control to IPMI. • IPMI (Intelligent Platform Management Interface) is a widely used legacy management interface for servers. It uses a simple UDP-based network protocol and security protocols unique to IPMI.

- SMASH (System Management Architecture for System Hardware) is the latest DMTF-defined management protocol. SMASH 2.0 defines a web-service protocol stack that uses SOAP-formatted messages, WSManagement, HTTP/S, TCP protocol stack with well accepted transport security.

### 10.2 Management Port

The onboard RJ45 can be configured as a dedicated management port or a shared 1-port GbE port. An on-board NC-SI connector will be populated on Ajax to support standard sideband interface to any add-in LAN cards.

### 10.3 Temperature Sensors

The motherboard should support these thermal sensors:
- Two to monitor temperatures for CPU0 and CPU1, retrieved through the CPU's temperature sensor interface (TSI)
- Inlet temperature, retrieved through the thermistor, and located in the front of the motherboard
- Outlet temperature, retrieved through the thermistor, and located in the rear of the motherboard

### 10.4 Fan Connections

The motherboard has fan tachometer and PWM connections to control the fans listed in section 7.1.

11 Power System This chapter describes the power sub-system for the Open Platform board platform.

### 11.1 Power Supply

| The silver box should be specified and designed to provide the highest efficiencies possible. The chassis will be designed such that it supports a redundant power supply. In addition, the power supply should meet the following criteria: • Power supply should have an minimum 90% efficiency • Power supply input should be TBD • Multi-output power supply output • PMBus interface support • Redundant and hot-swappable power supply support The board outline and initial specification was modeled using the Lite-on PS PS2112 supply. The output connector is card edge extension of PCB and blind mates with 32 position each side (Tyco 1761469(vertical) and 1761468(right angle) or FCI pn 10046971- 100LF (vertical) and 10053363-200LF (right angle). The mechanical design uses a straddle- mount version of these connectors (Part Number TBD).

### 11.2 Power Connector Pin-out

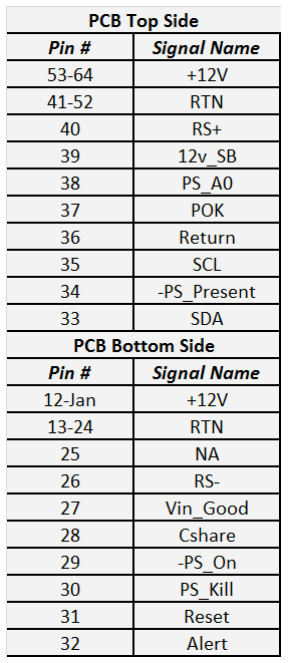
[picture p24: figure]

### 11.3 Support for Open Compute Infrastructure

The Open Compute Infrastructure supports three power bus bars that run along both sides of the back of an Open Compute Rack.
The Open Platform board will fit seamlessly into the open compute infrastructure by utilizing a PCB adapter (red board in the pictures below) that connects to the bus bar. In addition to interfacing with the open rack bus bars, this PCB will take the place of the silver box supplies and may provide any needed intermediate power conversion, such as 3.3V generation from 12V.
A conceptual drawing is shown below of Ajax in the Open Compute high PUE power distribution system.

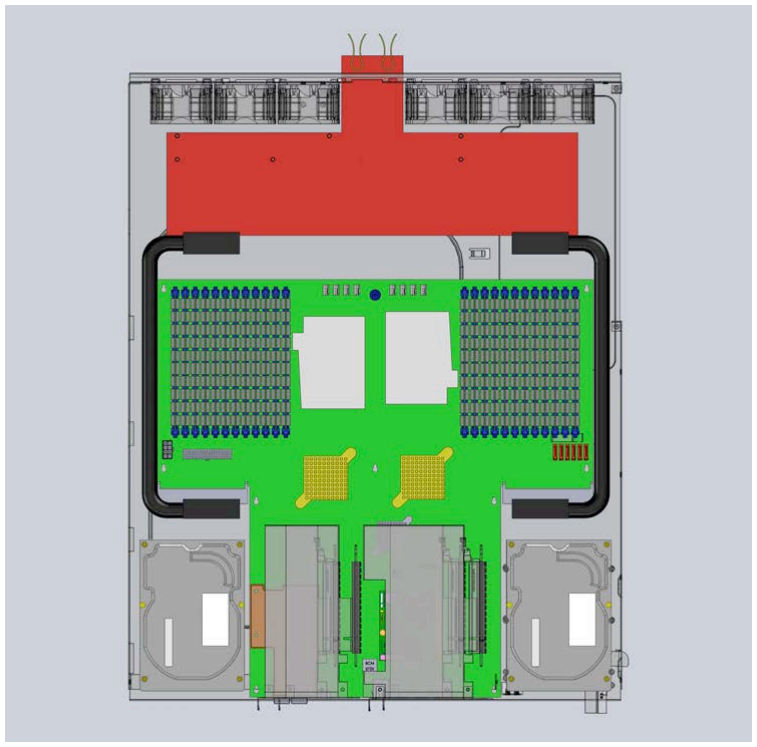
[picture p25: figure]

Figure 12 Open Compute Support for the Open Platform Board

### 11.4 Power Budget for Open Platform Board Configurations

The summarized power budget below is shown for three different configurations—HPC, General Purpose, and Storage. HPC has the highest performing, highest TDP CPUs, limited memory and IO. The 1U configuration is also the hardest configuration to cool and requires the highest power fans.
The general purpose configuration has more IO, standard power parts, fully populated DIMM slots, and uses SATA hard drives. The storage node is configured with 3 SAS controllers and fully populated memory.
It is important to note that these are maximum values. During production operation, bios controls can turn off features to significantly reduce power consumption from idle to 100%.
It is expected that the 3U storage node will use a different power supply than the 1U and 2U configurations.


Figure 13 Power Budget for the Open Platform Board

### 11.5 VRM Specifications

The VRM and motherboard should support PSI features that allow the VRM to run in its peak efficiency range, i.e. redundant phases on the VRM will be turned off when the processor is operating at a low power point. The CPU VRM solutions should be load line enabled and designed to fit the specified power loads only.
In addition, the voltage regulators with the following characteristics are recommended:
- Load line to minimize load step transient.
- Differential Sense for accurate voltage sensing.
- Support for high value, low ESR ceramic caps and low ripple noise.
- In general, the target for ripple from the regulator should be < 10% of the maximum allowable voltage range. This allows 90% for all other sources of noise.

11.5.1 Target Power Efficiencies
The following are the target power efficiencies for each given group:
- Core VR: > 90% across the full operating load
- DDR VR: > 90% across the full operating load
- Silverbox: > 90% depending on load

### 11.6 Power Sequencing

The Open Platform board should follow power sequencing requirements for the G34, SP5650, and SP5100. Specific sequencing requirements are outlined in available design guides.

### 11.7 Power Optimized Hardware Features

Section 5.2 and Section 5.3 describes the high level power optimized hardware and BIOS features needed for the Open Platform board.

11.7.1 Switching Regulators versus Linear Regulators
Because the Open Platform board is designed to maximize system power savings, careful consideration must be undertaken when designing power delivery to the various system components. There are cost and board space considerations to balance, but it is generally recommended that all voltage rails that consume more than 1W of power be implemented using more efficient switching solutions.
Specific space, cost, and efficiency tradeoffs should be carefully analyzed during the earliest stages of the design.

11.7.2 VDDR Implementation
In the past, VDDR and VLDT often shared a single regulator since both rails were specified for 1.2V operation. However, for low power designs, VDDR and VLDT should implement two separate regulators.

12 I/O System This section describes the motherboard's I/O features.

### 12.1 PCI-Express Slots

| A board fully populated with both SR56X0 chipset can support two x8 slots and two x 16 slots. The second tunnel chip is a stuff option for heavy I/O configurations. If populated with a 5690, the second tunnel provides enough lanes to feed two x16 slots. If populated with a 5650, two x8 slots are available. Section 7.1 describes the mechanical limitations (riser needed, low profile vs. standard, etc.) for each chassis height.

### 12.2 PCIe Mezzanine Card

| The motherboard has one mezzanine card connector that is intended for custom and modular 10Gb solutions. The mezzanine connector pin out and board outline are shown below and leverages the pin-out and board dimensions used in Open Compute 2.0 platforms.



Expected solutions to be evaluated include the Broadcom 57810, Mellanox Connect-X-2, and Solar Flare SFC9000. The Mellanox solution is an x8 Gen2 PCIe solution, while the Broadcom 57810 is a Gen3 PCIe solution. Solar Flare is an x8, Gen2 PCIe solution.

### 12.3 IMC Management Connector

Roadrunner provides support for an add-in management card solution that plugs into right angle connector on the motherboard. The motherboard connector is a 230-pin,


0.5mm pitch, right angle connector from Foxconn with a stack height of 7.8mm. The manufacturer part number is ASOB326-S78N-7F.

This connector accepts off the shelf management cards that adhere to the following pin-out and board outline. These management cards provide KVM support or basic server management in lieu of the BCM5725.

12.3.1 Board Outline

12.3.2 Pin-out
The pin-out is shown below. Additional signal descriptions are detailed separately in the AMD Management Connector Interface Design Guide.


### 12.4 Network

The motherboard has one BCM 5275 LAN chip on board to support the RJ45 connector. The BIOS supports PXE boot on the RJ45 port.
There is also a stuff option to provide support for the BCM5720. The BCM5720 is x2 PCI-Express 2.0 controller and has its own RJ45 connector on the motherboard. The NC-SI sideband interface connects to the management controller connector and is used to provide a management port if the BCM 5725 is not populated.
Each RJ45 connector has two built-in LEDs. While facing the RJ45 connector, the left LED is green single color; solid on means the link is active, and blinking means activity. The right LED is green/yellow dual color; green means 100M link speed while yellow means 1000M link speed.

### 12.5 USB Interfaces

The motherboard has two external USB ports located and the BIOS should support the following USB devices:
- Keyboard and mouse
- USB flash drive (bootable)
- USB hard drive (bootable)
- USB optical drive (bootable)

### 12.6 SATA

The motherboard has SP5100 interfaces on board, which support up to six SATA ports.

### 12.7 Debug Header

The motherboard includes a debug header on the front of the motherboard to display POST codes. The debug header supports hot plugging.
The debug card has two 7-segment LED displays, one RS-232 serial connector, and one reset switch. The RS-232 serial port provides console redirection. The two 7-segment LED displays show BIOS POST code and DIMM error information. The reset switch triggers a system reset when pressed.
The connector for the debug header is a 14-pin, shrouded, vertical, 2mm pitch connector. The debug card has a key to match with the notch to avoid pin shift when plugging in.


Figure 14 Debug Header


Figure 15 Debug Header Pin Definition

13 Environmental Requirements The motherboard meets the following environmental requirements: • Gaseous Contamination: Severity Level G1 per ANSI/ISA 71.04-1985 • Ambient operating temperature range: -5°C to +45°C. • Operating and storage relative humidity: 10% to 90% (non-condensing) • Storage temperature range: -40°C to +70°. • Transportation temperature range: -55°C to +85°C (short-term storage). The full OCP system also meets these requirements. In addition, the full system has an operating altitude with no de-ratings of 1000m (3300 feet).

### 13.1 Regulatory Compliance

| The 1U, 2U, and 3U Roadrunner platform implementations must also meet the following regulatory compliances: • FCC/CE Class "A" EMC • UL Safety Enabled

### 13.2 Vibration and Shock

| The motherboard meets shock and vibration requirements according to the following IEC specifications: IEC78-2-(*) and IEC721-3-(*) Standard & Levels. The testing requirements are listed below.

| Operating | Non-Operating
Vibration | 0.5g acceleration, 1.5mm amplitude, 5 to 500 Hz, 10 sweeps at 1 octave/minute for each of the three axes (one sweep is 5 to 500 to 5 Hz) | 1g acceleration, 3mm amplitude, 5 to 500 Hz, 10 sweeps at 1 octave/minute for each of the three axes (one sweep is 5 to 500 to 5 Hz)
Shock | 6g, half-sine 11mS, 5 shocks for each of the three axes | 12g, half-sine 11mS, 10 shocks for each of the three axes

Figure 16 Vibration and Shock Requirements

## 14 Prescribed Materials

### 14.1 Disallowed Components

| The following components are not used in the design of the motherboard: • Components disallowed by the European Union's Restriction of Hazardous Substances Directive (RoHS 6) • Trimmers and/or potentiometers • Dip switches

### 14.2 Capacitors and Inductors

| The following limitations apply to the use of capacitors: • Only aluminum organic polymer capacitors made by high quality manufacturers are used; they must be rated 105°C. • All capacitors have a predicted life of at least 50,000 hours at 45°C inlet air temperature, under worst conditions. • Tantalum capacitors are forbidden. • SMT ceramic capacitors with case size > 1206 are forbidden (size 1206 are still allowed when installed far from the PCB edge and with a correct orientation that minimizes risks of cracks). • Ceramic material for SMT capacitors must be X7R or better material (COG or NP0 type should be used in critical portions of the motherboard). Only SMT inductors may be used. The use of through hole inductors is disallowed.

15 Operating System Support Most up to date information about OS support is listed below.


Figure 17 Supported Operating Systems

16 Adherence to AMD Motherboard Design The expectation is that close partnership between AMD and a selected ODM will occur. This will include joint review of specification, schematic, stack-up, layout, thermal, and chassis design.

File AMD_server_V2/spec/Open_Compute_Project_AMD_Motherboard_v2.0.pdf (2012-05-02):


# AMD Motherboard Hardware v2.0

Author: Harry Li, Engineer Author: Amir Michael, Engineer

### 2 June 23, 2011

1 | Scope This document defines the technical specifications for the AMD motherboard used in Open Compute Project servers.
2 | Contents 1 Scope | 2 2 Contents | 2 3 Overview | 5 3.1 License | 5 3.2 CAD
Models | 5
| 4 Motherboard
Features | 6
| 4.1 Block
Diagram | 6
| 4.2 Placement

and

Form

Factor | 6
| 4.3 CPU

and

Memory | 8
| 4.4 Northbridge

PCI-‐E

Usage | 8
| 4.5 Southbridge/Peripheral

Bus

Controller | 8
| 5 BIOS | 9 5.1 BIOS
Chip | 9
| 5.2 BIOS
Socket | 9
| 5.3 BIOS

Source

Code | 9
| 5.4 BIOS

Configuration

and

Features | 9
| 5.5 BIOS

Setup

Menu | 9
| 5.6 Console
Redirect | 9
| 5.7 PXE Boot | 10 5.8 Other
Boot
Options | 10
| 5.9 Remote

BIOS

Update | 10
| 5.10 Event
Log | 10
| 6 Hardware

Monitoring

and

Fan

Speed

Control | 11
| 6.1 Thermal
Sensors | 11
| 6.2 Fan Connection | 12 7 Baseboard
Management
Controller | 12
| 7.1 Fan Speed
Control | 12

Open Compute Project AMD Motherboard Hardware v2.0

http://opencompute.org | 3

7.2 Power

7.4 Remote

Power
7.5 System

Event
7.6 Firmware

8.1 PSU
8.2 Fan
8.3 Motherboard
8.4 HDD

Power
8.5 Motherboard

Power-‐up
8.6 Hot

Swap
9 Power
9.1 Input
9.2 Hard

Drive
9.3 System

VRM
9.4 Power
10 I/O
10.1 PCI-‐E

x16

Slot/Riser
10.2 PCI-‐E

Mezzanine
10.3 PCI-‐E

External
10.4 DIMM

10.6 USB

10.8 Debug
10.9 Switches

and

11.2 Fixed
11.3 PCB
11.4 Heat

### 4 June 23, 2011

11.6 DIMM

Connector

Color | 26
12 Environmental
Requirements | 26
12.1 Vibration

and

Shock | 26
13 Prescribed
Materials | 26
13.1 Disallowed
Components | 26
13.2 Capacitors

and

Inductors | 27

http://opencompute.org | 5
3 | Overview
| When data center design and hardware design move in concert, they can improve efficiency and reduce power consumption. To this end, the Open Compute Project is a set of technologies that reduces energy consumption and cost, increases reliability and choice in the marketplace, and simplifies operations and maintenance. One key objective is openness—the project is starting with the opening of the specifications and mechanical designs for the major components of a data center, and the efficiency results achieved at facilities using Open Compute technologies. One component of this project is a custom motherboard. This document describes the Open Compute Project AMD motherboard, a dual AMD G34 socket motherboard with 16 DIMM slots. The motherboard is power-optimized and barebones, designed to provide the lowest capital and operating costs. Many features found in traditional motherboards have been removed from the design.
3.1 | License As of June 23, 2011, the following persons or entities have made this Specification available under the Open Web Foundation Final Specification Agreement (OWFa 1.0), which is available at http://www.openwebfoundation.org/legal/the-owf-1-0-agreements/owfa-1-0 Facebook, Inc. You can review the signed copies of the Open Web Foundation Agreement Version 1.0 for this Specification at http://opencompute.org/licensing/, which may also include additional parties to those listed above. Your use of this Specification may be subject to other third party rights. THIS SPECIFICATION IS PROVIDED "AS IS." The contributors expressly disclaim any warranties (express, implied, or otherwise), including implied warranties of merchantability, non- infringement, fitness for a particular purpose, or title, related to the Specification. The entire risk as to implementing or otherwise using the Specification is assumed by the Specification implementer and user. IN NO EVENT WILL ANY PARTY BE LIABLE TO ANY OTHER PARTY FOR LOST PROFITS OR ANY FORM OF INDIRECT, SPECIAL, INCIDENTAL, OR CONSEQUENTIAL DAMAGES OF ANY CHARACTER FROM ANY CAUSES OF ACTION OF ANY KIND WITH RESPECT TO THIS SPECIFICATION OR ITS GOVERNING AGREEMENT, WHETHER BASED ON BREACH OF CONTRACT, TORT (INCLUDING NEGLIGENCE), OR OTHERWISE, AND WHETHER OR NOT THE OTHER PARTY HAS BEEN ADVISED OF THE POSSIBILITY OF SUCH DAMAGE.
3.2 | CAD Models The following CAD files are incorporated by reference as if fully set forth in this specification:
| • TBD


### 6 June 23, 2011

4 | Motherboard Features
4.1 | Block Diagram

Figure 1 illustrates the functional block diagram of the motherboard.

Figure 1 Functional Block Diagram
4.2 Placement and Form Factor The motherboard's form factor is 6.6x20 inches. Figure 2 illustrates board placement. The placement shows the relative positions of key components, while exact dimension and position information is available in the DXF file and mechanical information is in the 3D CAD model. The ODM should strictly follow the form factor, PCI-E slot position, front IO port positions, PCI-E mezzanine card connector position, power connector, and mounting holes, while other components can be shifted based on layout routing as long as relative position is maintained. As shown in Figure 17, one Open Compute chassis accommodates two motherboards. In order to remove and install one board without affecting the other board, the following internal connectors are placed as close as possible to the front of the board in order to have easy frontal access: • One SATA signal connector and one SATA power connector. • Debug card header.


http://opencompute.org | 7

Figure 2 AMD Motherboard Component Placement

### 8 June 23, 2011

4.3 | CPU and Memory The motherboard supports two AMD G34 Magny Cours or Interlagos CPUs with a TDP (thermal design power) of 115W. The motherboard supports these features: • HT3 16x16 link HyperTransport™ links between CPUs with cHT3 target of up to 6.4 GT/s (with probe filter) • 1 ncHT3 16x16 link to SR56X0 chipset with target speed of up to 5.2 GT/s • Single Processor Mode • DDR3 direct attached memory support on cpu0 and cpu1 with: • 4 channels DDR3 registered memory interface on each CPU • 2 DDR3 slots per channel per processor (total of 16 DIMMs on the motherboard) • RDIMM/LV-RDIMM (1.35V/1.25V), LRDIMM, and UDIMM/LV-UDIMM (1.35V/1.25V) • SR, DR, and QR DIMMs • DDR3 speeds of 800/1066/1333/1600 • Up to maximum 512GB memory with 32GB RDIMMs
4.4 | Northbridge PCI-E Usage The motherboard supports PCI-E lane configuration as illustrated in Figure 3. Depending upon the chipset, different PCI-E interfaces are supported: • With the SR5650 chipset, the board supports one x16 PCI-E riser card. • With the SR5670 chipset, the board supports one x16 PCI-E riser card and one x4 PCI-E mezzanine card. • With the SR5690 chipset, the board supports one x16 PCI-E riser card, one x4 PCI-E mezzanine card, and one x4 PCI-E external connector.
Device | Number of PCI-E Lanes
x16 PCI-E slot | 16 (from GPP1)
x4 PCI-E mezzanine card | 4 (from GPP2[3:0], requires SR5670 or SR5690)
x4 PCI-E external connector (miniSAS) | 4 (from GPP3 [9:6], requires SR5690)
Intel 82576 NIC | 4 (from GPP3 [3:0])
Total number of lanes | 28

Figure 3 PCI-E Lane Usage
4.5 Southbridge/Peripheral Bus Controller The motherboard uses the AMD SP5100 Southbridge chipset, which supports the following features: • 2 USB 2.0 ports (on the front panel) • 6 SATAII ports • SPI interface • SMBUS interface (master and slave)

http://opencompute.org | 9
5 | BIOS
| The ODM is responsible for supplying and customizing a BIOS for the motherboard. The specific BIOS requirements are outlined in this section.
5.1 | BIOS Chip The BIOS uses the SP5100's SPI interface. The ODM is responsible for selecting a specific BIOS chip that meets the required functionality.
5.2 | BIOS Socket A socket on the motherboard holds the BIOS chip, which allows for manual replacement of the BIOS chip. The BIOS socket is easily accessible; other components on the motherboard do not interfere with the insertion or removal of the BIOS chip.
5.3 | BIOS Source Code The BIOS source code comes from AMI. The ODM is responsible for maintaining the BIOS source code to make sure it has latest code release from AMI and AMD.
5.4 | BIOS Configuration and Features The BIOS is tuned to minimize system power consumption. It has the following features: • Unused devices disabled, including PCI-E lanes, PCI, USB ports, and SATA/SAS ports • Tuning CPU/chipset settings to reach minimized power consumption and best performance • SPECpower is used as guidance for ODM to validate BIOS tuning results
5.5 | BIOS Setup Menu The ODM must provide a BIOS specification, which includes the complete BIOS, setup menu, and default settings. The setup menu allows its options to be configured before the operating system loads. The configuration options available through the boot menu include the following: • Settings to adjust memory speed, HT link speed, HT link width, and CPU Cx/Px power state. • Setting for power feature after AC failure; default is set to keep last state. • Setting for console redirection. Selectable options to support select console redirection from local COM port or the BMC's virtual UART for SOL. • Hardware health monitoring display. • Setting for watchdog timer; default is enabled and timeout value is 15 minutes. • Event log viewing and clearing. • Setting for ECC error threshold, available settings are 1, 4, 10, and 1000. • If a CMOS checksum error happens (for example, caused by a BIOS update), the BIOS loads the system default automatically after showing a text message in the console for 5 seconds and rebooting the system to apply the update without user input. • Setting to disable all "wait for keyboard input to continue" features.
5.6 | Console Redirect The BIOS detects the presence of a video card in the x16 PCI-E slot. If a video card is present, the BIOS directs its output to the video card. If no video card is present, the BIOS directs its output to the board-mounted RS-232 console output.

### 10 June 23, 2011

5.7 | PXE Boot The BIOS supports Intel PXE boot. When PXE booting, the system first attempts to PXE boot from the first Ethernet interface (eth0). If a PXE boot on the first Ethernet interface fails, the BIOS attempts to PXE boot from the second Ethernet interface (eth1).
5.8 | Other Boot Options The BIOS also supports booting from SATA and USB interfaces. The BIOS provides the capability to select boot options.
5.9 | Remote BIOS Update The BIOS can be updated remotely under these scenarios: • Scenario 1: Sample/Audit BIOS settings • Return current BIOS settings, or • Save/export BIOS settings in a human-readable form that can be restored/imported (as in scenario 2) • Scenario 2: Update BIOS with pre-configured set of BIOS settings • Update/change multiple BIOS settings • Reboot • Scenario 3: BIOS/firmware update with a new revision • Load new BIOS/firmware on machine and update, retaining current BIOS settings • Reboot Additionally, the update tool(s) should have the following capabilities: • Update from the operating system over the LAN – the OS standard is CentOS v5.2 • Can complete update with a single reboot (no PXE boot, no multiple reboots) • BIOS update or BIOS setup option change take no more than 5 minutes to complete • No user interaction (like prompts) • Can be scripted and propagated to multiple machines

### 5.10 Event Log

| The BIOS logs system events through the baseboard management controller (BMC).

5.10.1 Logged Errors
| • CPU/memory errors: Both correctable ECC and uncorrectable ECC errors should be logged into event log. Error categories include DRAM, HyperTransport™ Link, and L3 Cache. • HyperTransport™ errors: Any errors that have a status register should be logged into the event log. Fatal or non-fatal classification follows the chipset vendor's recommendation. • Internal parity errors: All errors that have status register should be logged into the event log. Fatal, non-fatal, or correctable classification follows the chipset vendor's recommendation. • PCI-E errors: All errors that have status register should be logged into Event Log, including root complex, endpoint device and any switch upstream/downstream

http://opencompute.org | 11

ports if available. Link disable on errors should also be logged. Fatal, non-fatal, or correctable classification follows the chipset vendor's recommendation.
- POST errors: All POST errors detected by the BIOS during POST should be logged into the event log.
- Power errors: Two power errors should get logged:
- When a 12.5VDC input power failure causes all power rails on the motherboard to lose power, including standby power.
- When an unexpected system shutdown occurs during system S0/S1 while 12.5VDC input is still valid.
- MHOT and PROCHOT errors: MEMHOT events should be logged with event source information indicating whether the event was triggered by a DIMM or a DIMM's voltage regulator. PROCHOT events should be logged with event source information indicating whether the event was triggered by a CPU or the CPU's voltage regulator.

5.10.2 Error Threshold Settings
An error threshold setting must be enabled for both correctable and uncorrectable errors. Once the programmed threshold is reached, an event should be triggered and logged.
- Memory Correctable ECC: The threshold value is 1000. When the threshold is reached, the BIOS should log the event including DIMM location information and output DIMM location code through the Facebook debug card.
- HyperTransport™ errors: Follow the chipset vendor's suggestion.
- PCI-E errors: Follow the chipset vendor's suggestion.
6 | Hardware Monitoring and Fan Speed Control
| The ODM needs to provide a system access interface and application to retrieve hardware monitoring sensor readings, including at minimum, lm_sensors, a Linux application for the CentOS operating system and its driver. The sensors to be read include voltage, temperature, and fan speed. The BMC can be used to monitor hardware and control fan speed. See section 7.
6.1 | Thermal Sensors The motherboard has five thermal sensors: • Two to monitor temperatures for CPU0 and CPU1, retrieved through the CPU's temperature sensor interface (TSI) • Northbridge temperature • Inlet temperature, retrieved through the thermistor, and located in the front of the motherboard • Outlet temperature, retrieved through the thermistor, and located in the rear of the motherboard The sensors should make sure that no CPU throttling is triggered due to thermal issues, under the following environmental conditions: • Inlet temperature lower than or equal to 30°C, and 0 inch H2O data center pressure with all fans in each thermal zone running functionally • Inlet temperature lower than or equal to 30°C, and 0.01 inch H2O pressure with one fan (or one rotor) in each thermal zone failing

### 12 June 23, 2011

6.2 | Fan Connection Each motherboard has fan tachometers and PWM connections to two system fans through the midplane.
7 | Baseboard Management Controller
| The BMC performs various functions for the motherboard, which are described in this section.
7.1 | Fan Speed Control The BMC provides a fan control algorithm that ensures adequate cooling of the system in the chassis. The BMC can update the FSC configuration both locally (through the CentOS host OS) and remotely (through OOB); these updates take effect immediately without rebooting.
7.2 | Power Monitoring The BMC supports platform power monitoring for the whole server. This is accessible both through in-band, and out-of-band by LAN or IPMB (Intelligent Platform Management Bus).
7.3 | Serial-Over-LAN The BMC supports serial-over-LAN (SOL) through the single shared network interface available on the motherboard.
7.4 | Remote Power Control The BMC supports remote system power on/off and reboot through LAN or IPMB.
7.5 | System Event Log The BMC supports a system event log. See section 5.10 for more information.
7.6 | Firmware Update The ODM must provide tool(s) to implement remote BIOS firmware update, which does not require any physical input at the system. Remote update means either through out- of-Band by the BMC or through logging into the local OS (CentOS 5.2) over the network.

http://opencompute.org | 13
8 | Midplane
| The midplane is a PCB board that functions as a bridge between the system fans, power supply (PSU), and both motherboards. Its form factor is 2x13.4 inches.
8.1 | PSU Connector The midplane has one FCI 51939-582 male right angle header, which is mated directly with the PSU for 12.5VDC input. Figure 4 shows the pin definition and direction based on the PSU.
Pin # | Signals | Direction | Description | Usage
P1, P2 | P12V | Power | 12.5VDC | 12.5VDC
P3, P4 | GND | Power | Ground | Ground
A1 | AUX_RTN_GND | | Signal return | NC
A2 | BACKUP_N | Output | PSU backup mode indication | NC
B1 | SHARE_SEL_1 | Input | PSU mode selection | NC
B2 | SHARE_SEL_2 | Input | PSU mode selection | NC
C1 | GREEN_LED_N | Output | Low active | Connect to bi-color LED
C2 | YELLOW_LED_N | Output | Low active | Connect to bi-color LED
D1 | RED_LED_N | Output | Low active | Connect to LED
D2 | P5V_AUX | Power | 5V for LED, 50mA limited | LED power

Figure 4 Midplane to PSU Connector Pin Definition
For the PSU LED, the midplane provides a 4-pin vertically shrouded 2.54mm pitch header with latch. This allows an LED cable to extend the PSU LED to the chassis front. The PSU connector pins C1 and C2 connect to one bi-color (green/yellow) LED with a common anode. Pin D1 is connected to one red LED. Pin D2 is 5V and used for an LED anode. Both are 3mm LEDs. A current limit resistor is required for each LED signal.
Pin | Description
1 | GREEN_LED_N
2 | YELLOW_LED_N
3 | RED_LED_N
4 | P5V_AUX

Figure 5 PSU LED Header Pin Definition
When the PSU's red LED blinks (at 1Hz, 50% duty-cycle), it indicates a PSU fan failure.
8.2 Fan Connectors The midplane has connectors for the four system fans. The connector signals comply both mechanically and electrically with the specifications defined in the 4-Wire Pulse Width Modulation (PWM) Controlled Fans Specification Revision 1.3 September 2005 published by Intel Corporation. Each fan is driven by dedicated PWM signal. Figure 6 defines the proper pin-out of the connector.

### 14 June 23, 2011

Pin | Description
1 | GND
2 | 12VDC
3 | Sense
4 | Control

Figure 6 Fan Header Pin-out
A fan tachometer signal from each fan is routed to acquire fan speed. The midplane directly delivers 12.5V power to the fan connector. If one motherboard is not powered on, then its two corresponding fans are turned off to save power.
8.3 | Motherboard Connectors The midplane has two FCI 51770-044 female right-angle power/signal connectors (2P+16S+2P: 4 power blades and 16 signals). The motherboard with mated FCI 51730-162 male right angle header slides in and mates with one of the FCI headers on the midplane. Figure 7 shows the pin definition of the 2P+16S+2P connector; the direction is based on the midplane.
Pin # | Signal | Direction | Description
P1, P2 | P12V | Power | 12.5VDC
P3, P4 | GND | Power | Ground
A1 | SMB_ALT_N | Output | SMBUS alert signal from hot-‐swap controller
A2 | TACH1A | Output | Reserved for extra fan tachometer on FAN1
A3 | TACH2A | Output | Reserved for extra fan tachometer on FAN2
A4 | RSVD | | Reserved for future
B1 | SCLK | Bi-‐direction | SMBUS CLOCK
B2 | SDATA | Bi-‐direction | SMBUS DATA
B3 | MB_ON | Input | Indicates that motherboard starts powered on
B4 | PSU_PG | Output | High active, indicates that PSU 12.5VDC output is ready
C1 | FAN1_TACH | Output | System fan #1 tachometer
C2 | FAN1_PWM | Input | System fan #1 PWM
C3 | FAN2_TACH | Output | System fan #2 tachometer
C4 | FAN2_PWM | Input | System fan #2 PWM
D1 (short pin) | MATED_N | Input | Low active, indicates motherboard is fully mated
D2 | MATED_GND_RTN | | Connected to GND in midplane
D3 | MB_ID | Output | Motherboard ID = 0 (left), 1 (right)
D4 | FAN_FAIL_N | Output | PSU fan failure detected

http://opencompute.org | 15

Figure 7 Midplane to Motherboard Connector Pin Definition
8.4 | HDD Power Connector The midplane has two HDD 4-pin power connectors, allowing for the routing of two HDD power cables directly from the midplane to the two hard drives.
8.5 | Motherboard Power-up Delay While running on AC power, in order to avoid both motherboards powering up at the same time and drawing larger than normal current, the midplane introduces a delay between the 12.5V power delivered to each of the two motherboards. The delay time can be set between 1 second and 1 minute, with 30 seconds as the default configuration. The power-up delay behaves as follows: • When both MB0 and MB1 are installed and AC power is applied, MB0 powers on first, then after 30 seconds (the timer delay), MB1 powers on. • When both MB0 and MB1 are operating, and you remove and re-insert a motherboard, there is no delay for it to power on again. • When only MB0 is installed and AC power is applied, there is no delay when it powers on. • When only MB1 is installed and AC power is applied, there is no delay when it powers on. • With one motherboard is operating, and another motherboard is inserted, there is no delay when it powers on. • If no motherboards are installed and AC power is applied, then both MB0 and MB1 are inserted, there is a 30 second timer delay between MB0 and MB1 powering on.
8.6 | Hot Swap Controller In order to have better control of the 12.5VDC power input to each motherboard, the ODM should include two hot swap controllers (one for each motherboard) on the midplane. The hot swap controller provides: • Inrush current control when the motherboard is inserted and the server is powered on. • Current limiting protection for short circuits. • PMBUS interface to enable the BMC to report server input power.
9 | Power System
9.1 | Input Voltage
9.1.1 | Input Voltage Level The nominal input voltage delivered by the power supply is 12.5VDC. The motherboard can accept and operate normally at an input voltage tolerance range between 10.8V and 13.2V. The motherboard's under-voltage protection level is 10V or below.
9.1.2 | Capacitive Load To ensure compatibility with the system power supply, the motherboard cannot have a capacitive load greater than 4000µF. The capacitive load of the motherboard should not

Pin 1; Motherboard component side

### 16 June 23, 2011

exceed the maximum value of 4000µF under any operating condition listed in section 12, which defines environmental conditions.

9.1.3 | Input Connector The power input connector is an FCI 51730-162 male right-angle header. CPU Voltage Regulation Module (VRM)
9.1.4 | CPU Maximum Power The motherboard can handle a processor with a maximum thermal design power (TDP) of 115W.
9.1.5 | CPU VRM Optimizations The CPU VRM is optimized to reduce cost and increase the efficiency of the power conversion system. The ODM should only use the minimum number of required phases to support the maximum CPU power defined in section 4.3. A PSI (power state indicator) allows the shedding of unused phases, letting the VRM operate at its peak efficiency.
9.1.6 | CPU VRM Efficiency The minimum efficiency for the CPU VRM is 91% over the 30% to 90% load range and 93% over the 50% to 70% load range for TDP 115W CPU, measured from the 12.5V input to the VRM output.
9.2 | Hard Drive Power The motherboard supplies power to the system's six hard drives. The drives require 12VDC and 5VDC power sources. For one individual SATA port, power is delivered through a traditional 4-pin floppy disk power connector described in Figure 8.
Pin | Description
1 | +5VDC
2 | GND
3 | GND
4 | +12VDC

Figure 8 Drive Power Connector

http://opencompute.org | 17

For the other five SATA ports, power is delivered through a 4-pin (2x2) ATX power connector, which fans out to five standard SATA power cables. Pin definition is described in Figure 9.

### 18 June 23, 2011

Pin | Description
1 GND
2 GND
3 +5VDC
4 +12VDC

Figure 9 4 Pin ATX Power Connector

9.2.1 | Power Requirements The motherboard must deliver enough current on both the 12.5VDC and 5VDC rails to power all 6 hard drives this platform supports. The PCB traces must support 1A of continuous power per HDD (6A total) on the 12.5VDC power rail, and 0.75A of continuous power per HDD (4.5A total) on the 5VDC power rail. It must support the inrush current required by each drive.
9.2.2 | Output Protection The 5V disk output power regulator protects against shorts and overload conditions.
9.2.3 | Spin-up Delay When the hard drive spins up after the system powers on, it draws excessive current on both 12V and 5V. The peak current may reach 1.5A - 2A range in 12V. Each of the system's six hard drives must spin up in sequence. As an option, the BIOS can implement a 5 second delay between each hard drive spinning up. To enable the hard drive's spin-up delay function, set pin 11 of the SATA hard drive's power cable to NC (No Connection).
9.3 | System VRM Efficiency The ODM must supply high efficiency VRMs for all other voltage regulators over 20W not defined in this specification. All voltage regulation modules over 20W must have 91% efficiency over the 30% to 90% load range.
9.4 | Power State The motherboard returns to the previous power state upon application of power to the input connector. The use of a power button is not required. The motherboard always resumes operation upon restoration of power in a power failure event if the previous power state is power on.

## 10 I/O System

| This section describes the motherboard's I/O features.

### 10.1 PCI-E x16 Slot/Riser Card

| The motherboard has one PCI-E x16 slot, which holds an x16 PCI-E Gen 2 signal from Northbridge (SR56x0). The slot location is described in the mechanical DXF file. The motherboard also has a PCI-E riser card so two standard profile PCI-E cards (4.376"

http://opencompute.org | 19

maximum height and 6.6" maximum length, based on the PCI Express Card Electromechanical Specification Rev 2.0) can be inserted horizontally and locked in position.

### 10.2 PCI-E Mezzanine Card

The motherboard has one PCI-E x4 mezzanine card connector that holds the x4 PCI-E Gen 2 signal from Northbridge (SR5670).

### 10.3 PCI-E External Connector

The motherboard has one PCI-E x4 (miniSAS) external connector on board. This PCI-E x4 connector can be used to build a PCI-E connection between two systems.
The x4 connector can be hot inserted and removed. A PCI-E re-driver is used for PCI-E external links and supports a miniSAS cable up to 2 meters long.
The connector is a miniSAS-4i right-angle connector. The external PCI Express target device is TBD. Figure 10 shows the external PCI-E pin assignments. The design follows the PCI Express External Cabling 1.0 Specification (http://www.pcisig.com/members/downloads/specifications/pciexpress/PCI_Express_External_Cabling_Rev1.0_updated.pdf).
Pin Numbers | Signals | Description
A2/A3, A5/A6, A13/A14, A16/A17 | PER{0..3}{P/N} | Differential PCI Express receiver lanes
A1, A4, A7, A12, A15, A18 | GND | Ground reference for Differential PCI Express lanes
A8 | CPRSNT# | Cable installed/downstream subsystem powered up
A9 | CPWRON | Upstream subsystem's power valid notification
A10 | CWAKE# | Power management signal for wakeup events (optional)
A11 | CPERST# | Cable PERST#
B2/B3, B5/B6, B13/B14, B16/B17 | PET{0..3}{P/N} | Differential PCI Express transmitter lanes
B1, B4, B7, B12, B15, B18 | GND | Ground reference for Differential PCI Express lanes
B8 | SCLK/TX | SMBUS (BMC) CLOCK (optional UART TX from SIO)
B9 | SDATA/RX | SMBUS (BMC) DATA (optional UART RX from SIO)
B10 | 3.3V/SYS_RST# | 3.3V standby with 0 ohm in series (reset signal to trigger system reset)
B11 | SB_RTN | Signal return for single-ended sideband signals

Figure 10 External PCI-E Pin Assignments

### 10.4 DIMM Connector

The motherboard uses a 30u" gold contact for the DDR3 DIMM through-hole connector.

### 10.5 Network

The motherboard has one 82576 LAN chip on board to support the RJ45 connector in the front. The BIOS supports PXE boot on the RJ45 port.

### 20 June 23, 2011

Each RJ45 connector has two built-in LEDs. While facing the RJ45 connector, the left LED is green single color; solid on means the link is active and blinking means activity. The right LED is green/yellow dual color; green means 100M link speed while yellow means 1000M link speed.

10.5.1 Reboot on WOL in S0 State
Reboot on WOL (ROW) is a feature that repurposes the traditional Wake on LAN (WOL) signal to reboot the motherboard. While the system is in S0 state (running), when a WOL packet is received by the NIC, the wakeup signal generated by the NIC causes a hardware rebo0ot of the motherboard. This is accomplished by tying the WOL interrupt pin of the NIC to the system's master reboot signal. ROW does not require the power supply to cycle its output.
There is an optional ROW connection for the WAKE# signal from PCI-E slot and external PCI-E connector, which gives optional ROW support for add-in cards and external PCI-E devices.
ROW is enabled by the NIC EEPROM, so the appropriate NIC EEPROM for the 82576 chip must be used. The motherboard also supports ROW on both the PCI-E LAN card and the mezzanine LAN card, which includes hardware circuit support and NIC EEPROM enabling.

10.5.2 Out of Band Network Access
The motherboard supports out of Band (OOB) network access to the BMC through network interfaces on the 82576 chip. This includes all remote access features described in this specification.

### 10.6 USB Interfaces

The motherboard has two external USB ports located in the front of the motherboard. The BIOS supports the following USB devices:
- Keyboard and mouse
- USB flash drive (bootable)
- USB hard drive (bootable)
- USB optical drive (bootable)

### 10.7 SATA

The motherboard has SP5100 interfaces on board, which support up to six SATA ports. The hard drives attached to the SATA connectors follow the spin-up delay described in section 9.2.3.

### 10.8 Debug Header

The motherboard includes a debug header on the front of the motherboard to display POST codes (see 10.8.1). The debug header supports hot plugging.
The debug card has two 7-segment LED displays, one RS-232 serial connector, and one reset switch. The RS-232 serial port provides console redirection. The two 7-segment LED displays show BIOS POST code and DIMM error information. The reset switch triggers a system reset when pressed.


http://opencompute.org | 21

The connector for the debug header is a 14-pin, shrouded, right angle, 2mm pitch connector. Figure 11 is an illustration of the headers. The debug card has a key to match with the notch to avoid pin shift when plugging in.

Figure 11 Debug Header

Pin (CKT) | Function
1 Low HEX character [0] least significant bit 2 Low HEX character [1]
3 Low HEX character [2]
4 Low HEX character [3] most significant bit 5 High HEX character [0] least significant bit 6 High HEX character [1]
7 High HEX character [2]
8 High HEX character [3] most significant bit 9 Serial transmit (motherboard transmit) 10 Serial receive (motherboard receive)
11 System reset
12 Serial console select (1=SOL; 0=local) 13 GND
14 VCC (+5VDC)

Figure 12 Debug Header Pin Definition

10.8.1 Post Codes
POST codes are sent to the debug header in hexadecimal format via two hex codes. The hex codes can be driven by either the legacy parallel port (port 80) on the SIO, or 8 GPIO pins.
During the boot sequence the BIOS initializes and tests each DIMM. If a module fails initialization or does not pass the BIOS test, the following POST codes should flash on the debug card to indicate which DIMM has failed. The first hex character indicates which CPU interfaces the DIMM module; the second hex character indicates the number of the DIMM module. The BIOS flashes the corresponding hex code indefinitely to allow time for a technician to service the system. The DIMM number count starts from the DIMM furthest from the CPU.


### 22 June 23, 2011

| Code | Result
CPU0 | A0 | CPU0 DIMM0 (furthest) failure
| A1 | CPU0 DIMM1 failure
| A2 | CPU0 DIMM2 failure
| A3 | CPU0 DIMM3 failure
| A4 | CPU0 DIMM4 failure
| A5 | CPU0 DIMM5 failure
| A6 | CPU0 DIMM6 failure
| A7 | CPU0 DIMM7 failure
CPU1 | B0 | CPU1 DIMM0 (furthest) failure
| B1 | CPU1 DIMM1 failure
| B2 | CPU1 DIMM2 failure
| B3 | CPU1 DIMM3 failure
| B4 | CPU1 DIMM4 failure
| B5 | CPU1 DIMM5 failure
| B6 | CPU1 DIMM6 failure
| B7 | CPU1 DIMM7 failure

Figure 13 DIMM Error Code Table

Figure 14 DIMM Numbering Silkscreen

http://opencompute.org | 23

10.8.2 Serial Console
The output stage of the system's serial console is contained on the debug card. The TX and RX signals from the SIO are sent to the debug header at the chip's logic levels (+3.3V). The debug card contains the RS-232 level shifter and the RS-232 D-9 connector.
By default, the host does console redirection through serial over LAN (SOL, see 7.3).
When the debug card is connected, debug card pin 12 is used to select console redirection between SOL and the local serial port on the card, as described in Figure 12.

### 10.9 Switches and LEDs

The motherboard includes a power switch, reset switch, power LED, HDD activity LED, and beep error LED.

10.9.1 Switches
The front edge of the PCB has right angle pushbutton switches. One switch is used as the system's power button the second switch is used at the system's reset button.
If the power switch is depressed for less than four seconds, a power management event is issued, indicating that the power switch has been triggered. If the power switch is depressed for more than four seconds, the motherboard performs a hard power off.
If the reset switch is depressed for any length of time, the motherboard performs a hard reset and begins executing the BIOS initialization code.
Each switch is identified by a label on the motherboard's silkscreen.

10.9.2 LEDs
The motherboard has 3 LEDs on the front edge. Figure 15 identifies each LED's color, function, and silkscreen label. The silkscreen describes the functionality of each LED.
LED Color | Function | Silkscreen Label
Blue | Power LED. This LED has the same functionality of a traditional PC power LED. It illuminates only if the motherboard is in the powered on state. | PWR
Green | Hard drive activity. This LED illuminates when there is activity on the motherboard's SATA hard drive interfaces. | HDD
Yellow | This LED replaces the functionality of the PC speaker. The motherboard causes the LED to illuminate for the same duration and sequence as the PC speaker would normally beep. The LED allows for easier diagnosis in a noisy data center environment. | BEEP

Figure 15 LED Functionality

### 24 June 23, 2011

The beep error LED patterns are described in Figure 16.

Error Description | LED Patterns
Memory refresh timer error | On (2s) | Off (0.25s) | On (2s) | Off (0.25s) | On (2s) | Off (3s) | …(repeat)
Base memory read/write test error | On (2s) | Off (0.25s) | On (2s) | Off (0.25s) | On (0.25s) | Off (3s) | …(repeat)
Keyboard controller BAT test error | On (0.25s) | Off (0.25s) | On (0.25s) | Off (0.25s) | On (2s)
General exception error | On (2s) | Off (0.25s) | On (0.25s) | Off (0.25s) | On (0.25s) | Off (3s) | …(repeat)
Display memory error | On (0.25s) | Off (0.25s) | On (0.25s) | Off (0.25s) | On (0.25s)

Figure 16 Beep Error LED Patterns


http://opencompute.org | 25

## 11 Mechanical

### 11.1 Dimensions

Figure 17 shows the basic view of the Open Compute Project server chassis. Refer to the mechanical step file provided for detailed information.

Figure 17 Open Compute Project Server Chassis for AMD Motherboards

### 11.2 Fixed Locations

Refer to the mechanical DXF file for the fixed locations of the mounting hole, PCI-E x16 slot, and power connector.

### 11.3 PCB Thickness

To ensure proper alignment of the FCI power connector and mounting within the mechanical enclosure, the PCB thickness of both the motherboard and midplane are 85mil (2.16mm).

### 11.4 Heat Sinks

The motherboard supports heat sinks that are mounted according to the AMD G34 heat sink specification. The mounting device employs a backplate and receptacles for screw-down type heat sinks. The ODM must comply with all keep out zones defined by AMD.

### 11.5 Silkscreen

The silkscreen is white in color and includes labels for these components:
- cpu0/cpu1
- eth0
- DIMM slot numbering
- LEDs, as defined in 10.9.2
- Switches, as defined in 10.9.1

### 26 June 23, 2011

### 11.6 DIMM Connector Color

Colored DIMM connectors indicate the first DIMM of each memory channel, whereas the remaining DIMM connectors on the same memory channel are a different color. The first DIMM on each channel is defined as the DIMM placed physically furthest from its associated CPU. This DIMM connector must be populated first when memory is only partially populated.

## 12 Environmental Requirements

The motherboard meets the following environmental requirements:
- Gaseous Contamination: Severity Level G1 per ANSI/ISA 71.04-1985
- Ambient operating temperature range: -5°C to +45°C
- Operating and storage relative humidity: 10% to 90% (non-condensing)
- Storage temperature range: -40°C to +70°C
- Transportation temperature range: -55°C to +85°C (short-term storage) The full OCP system meets the following environmental requirements:
- Altitude up to 1000m above sea level
- System inlet temperature between 18°C and 30°C
- Humidity between 30% and 85%

### 12.1 Vibration and Shock

The motherboard meets shock and vibration requirements according to the following IEC specifications: IEC78-2-(*) and IEC721-3-(*) Standard & Levels. The testing requirements are listed in Figure 18.

| Operating | Non-Operating
Vibration | 0.5g acceleration, 1.5mm amplitude, 5 to 500 Hz, 10 sweeps at 1 octave/minute for each of the three axes (one sweep is 5 to 500 to 5 Hz) | 1g acceleration, 3mm amplitude, 5 to 500 Hz, 10 sweeps at 1 octave/minute for each of the three axes (one sweep is 5 to 500 to 5 Hz)
Shock | 6g, half-sine 11mS, 5 shocks for each of the three axes | 12g, half-sine 11mS, 10 shocks for each of the three axes

Figure 18 Vibration and Shock Requirements

## 13 Prescribed Materials

### 13.1 Disallowed Components

The following components are not used in the design of the motherboard:
- Components disallowed by the European Union's Restriction of Hazardous Substances Directive (RoHS 6)
- Trimmers and/or potentiometers
- Dip switches

http://opencompute.org | 27

### 13.2 Capacitors and Inductors

The following limitations apply to the use of capacitors:
- Only aluminum organic polymer capacitors made by high quality manufacturers are used; they must be rated 105°C
- All capacitors have a predicted life of at least 50,000 hours at 45°C inlet air temperature, under worst conditions
- Tantalum capacitors are forbidden
- SMT ceramic capacitors with case size > 1206 are forbidden (size 1206 are still allowed when installed far from the PCB edge and with a correct orientation that minimizes risks of cracks)
- Ceramic material for SMT capacitors must be X7R or better material (COG or NP0 type should be used in critical portions of the motherboard)
Only SMT inductors may be used. The use of through hole inductors is disallowed.

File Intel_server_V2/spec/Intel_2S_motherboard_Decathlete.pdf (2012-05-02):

# Enterprise-Ready 2S Efficient Performance Intel Motherboard Specification

# Intel® Xeon® processor E5-2600 product family


Revision 0.5

April 2012

Enterprise-Ready 2S Efficient Performance Intel Motherboard Specification

Intel® Confidential | Revision 0.5
ii

## Revision History

Date | Revision Number | Modifications
April 2012 | 0.5 | First Draft

## Disclaimers

INFORMATION IN THIS DOCUMENT IS PROVIDED IN CONNECTION WITH INTEL PRODUCTS. NO LICENSE, EXPRESS OR IMPLIED, BY ESTOPPEL OR OTHERWISE, TO ANY INTELLECTUAL PROPERTY RIGHTS IS GRANTED BY THIS DOCUMENT. EXCEPT AS PROVIDED IN INTEL'S TERMS AND CONDITIONS OF SALE FOR SUCH PRODUCTS, INTEL ASSUMES NO LIABILITY WHATSOEVER AND INTEL DISCLAIMS ANY EXPRESS OR IMPLIED WARRANTY, RELATING TO SALE AND/OR USE OF INTEL PRODUCTS INCLUDING LIABILITY OR WARRANTIES RELATING TO FITNESS FOR A PARTICULAR PURPOSE, MERCHANTABILITY, OR INFRINGEMENT OF ANY PATENT, COPYRIGHT OR OTHER INTELLECTUAL PROPERTY RIGHT.

A "Mission Critical Application" is any application in which failure of the Intel Product could result, directly or indirectly, in personal injury or death. SHOULD YOU PURCHASE OR USE INTEL'S PRODUCTS FOR ANY SUCH MISSION CRITICAL APPLICATION, YOU SHALL INDEMNIFY AND HOLD INTEL AND ITS SUBSIDIARIES, SUBCONTRACTORS AND AFFILIATES, AND THE DIRECTORS, OFFICERS, AND EMPLOYEES OF EACH, HARMLESS AGAINST ALL CLAIMS COSTS, DAMAGES, AND EXPENSES AND REASONABLE ATTORNEYS' FEES ARISING OUT OF, DIRECTLY OR INDIRECTLY, ANY CLAIM OF PRODUCT LIABILITY, PERSONAL INJURY, OR DEATH ARISING IN ANY WAY OUT OF SUCH MISSION CRITICAL APPLICATION, WHETHER OR NOT INTEL OR ITS SUBCONTRACTOR WAS NEGLIGENT IN THE DESIGN, MANUFACTURE, OR WARNING OF THE INTEL PRODUCT OR ANY OF ITS PARTS.

This specification is not a “Contribution” as that term is used under the Open Web Foundation Contributors License Agreement.

Intel may make changes to specifications and product descriptions at any time, without notice. Designers must not rely on the absence or characteristics of any features or instructions marked "reserved" or "undefined". Intel reserves these for future definition and shall have no responsibility whatsoever for conflicts or incompatibilities arising from future changes to them. The information here is subject to change without notice. Do not finalize a design with this information.

The products described in this document may contain design defects or errors known as errata which may cause the product to deviate from published specifications. Current characterized errata are available on request.

Contact your local Intel sales office or your distributor to obtain the latest specifications and before placing your product order.

Copies of documents which have an order number and are referenced in this document, or other Intel literature, may be obtained by calling 1-800-548-4725, or go to: http://www.intel.com/design/literature.htm

Intel, the Intel logo, and Xeon are trademarks or registered trademarks of Intel Corporation.

*Other brands and names may be claimed as the property of others.

Copyright © 2012 Intel Corporation. All rights reserved.

Revision 0.5 | Intel® Confidential | 1

## Table of Contents

Intel®
2 | Confidential | Revision 0.5

## 1. Introduction

This Technical Product Specification (TPS) provides board-specific information detailing the features, functionality, and high-level architecture of the Enterprise-ready 2S Efficient Performance Intel® Motherboard based on the Intel® Xeon®

processor E5-2600 product family and the Intel® C602 (-A) chipset.

The Intel® Xeon®

processor E5-2600 product family and the Intel® C602 (-A) chipset provide a platform capable of supporting features and functions attractive to a number of market segments. The purpose of this document is to define a dual socket server board that is capable of deployment in scale out data centers as well as traditional data centers with 19” rack enclosures. Intel’s intent is to provide a platform that enables server vendors to leverage a single design across multiple market segments via multiple board SKUs.

4 | Confidential | Revision 0.5

## 2. Product Overview

Table 1 shows the requirements that a design must meet in order to be considered a compliant Intel® dual socket server board.

Table 1. Intel®
Server Board Feature Set
Feature | Description
Processor Support | ▪ Two LGA2011 (Socket R) processor sockets ▪ Support for one or two Intel® Xeon® processors E5-2600 product family ▪ Support for the full range of processors offered, although a board may be optimized for a particular processor TDP level (i.e. VR phases removed to optimize for lower power processors)
Memory | ▪ 8 – 24 DIMM slots ▪ Unbuffered DDR3 (UDIMM), registered DDR3 (RDIMM), Load Reduced DDR3 (LRDIMM) ▪ Memory DDR3 data transfer rates of 800, 1066, 1333 MT/s, and 1600 MT/s ▪ DDR3 standard I/O voltage of 1.5V and DDR3 Low Voltage of 1.35V
Chipset | Intel® C602 (-A) chipset with support for optional Storage Option Select keys
External I/O connections | ▪ May support DB-15 Video connector ▪ Shall support at least two RJ-45 Network Interface Connectors supporting 10/100/1000Mb ▪ Shall support at least two USB 2.0 connectors
I/O Module Options | The following I/O module options may be supported. Installed I/O modules shall be supported in addition to standard on-board features and any add-in expansion cards. ▪ Quad port 1 GbE module ▪ Dual port 10GBase-T Ethernet module ▪ Dual SFP+ port 10GbE module ▪ Single Port FDR speed InfiniBand module with QSFP connector
System Fans | ▪ Managed system fan headers
PCIe* Adapter Card Support | ▪ Two half-length x8 PCIe* adapter cards for 1U chassis ▪ Three x8 PCIe* Adapter cards for 2u chassis with at least one full length
Video | ▪ May contain a 2D Video Controller ▪ 16 MB DDR3 Memory
Storage | ▪ Two single port AHCI SATA connectors capable of supporting up to 6 Gb/sec ▪ Two SCU 4-port mini-SAS connectors capable of supporting up to 3 Gb/sec SATA/SAS ▪ RAID 0/1/10/5
Security | ▪ May Intel® Trusted Platform Module (TPM)
Server Management | ▪ Integrated Baseboard Management Controller, IPMI 2.0 compliant ▪ Support for DCMI 1.5

### 2.1 Server Board Dimensional Mechanical Drawing


Figure 1. Motherboard maximum dimensions


6 | Confidential | Revision 0.5

Figure 2. 24 DIMM Motherboard Concept

## 3. Product Architecture Overview

The following diagram provides an overview of the server board architecture, showing the features and interconnects of each of the major sub-system components of the Intel® Xeon®
processor E5-2600 product
family and the Intel® C602 (-A) chipset.


Figure 3. Intel®

Xeon®
processor E5-2600 product family Functional Block Diagram

### 3.1 Processor Support

The server board shall support two Socket-R (LGA2011) processor sockets and the full range of the Intel® Xeon®
processor E5-2600 product family.

8 | Confidential | Revision 0.5

Note: Previous generation Intel® Xeon®
processors are not supported on the Intel server boards described in this document.

Visit the Intel web site for a complete list of supported processors.

### 3.2 Supported Memory

Table 2. UDIMM Support Guidelines

Ranks Per DIMM & Data Width | Memory Capacity Per DIMM¹ | Speed (MT/s) and Voltage Validated by Slot per Channel (SPC) and DIMM Per Channel (DPC)
2 Slots per Channel Intel® Server Board S2600GL | 3 Slots per Channel Intel® Sever Board S2600GZ
1DPC | 2DPC | 1DPC | 2DPC
1.35V | 1.5V | 1.35V | 1.5V | 1.35V | 1.5V | 1.35V | 1.5
SRx8 ECC | 1GB | 2GB | 4GB | 1066, 1333 | 1066, 1333 | 1066 | 1066, 1333 | 1066 | 1066, 1333 | 1066 | 1066, 1333
ECC DRx8 | 2GB | 4GB | 8GB | 1066, 1333 | 1066, 1333 | 1066 | 1066, 1333 | 1066 | 1066, 1333 | 1066 | 1066, 1333

Table 3. RDIMM Support Guidelines

Ranks Per DIMM & Data Width | Memory Capacity Per DIMM¹ | Speed (MT/s) and Voltage Validated by Slot per Channel (SPC) and DIMM Per Channel (DPC)
2 Slots per Channel Intel® Server Board S2600GL | 3 Slots per Channel Intel® Sever Board S2600GZ
1DPC | 2DPC | 1DPC | 2DPC | 3DPC
1.35V | 1.5V | 1.35V | 1.5V | 1.35V | 1.5V | 1.35V | 1.5V | 1.35V | 1.5
SRx8 | 1GB | 2GB | 4GB | 1066 1333 | 1066 1333 1600 | 1066, 1333 | 1066 1333 1600 | 1066, 1333 | 1066 1333 1600 | 1066, 1333 | 1066 1333 1600 | n/a | 800, 1066
DRx8 | 2GB | 4GB | 8GB | 1066 1333 | 1066 1333 1600 | 1066 1333 | 1066 1333 1600 | 1066, 1333 | 1066 1333 1600 | 1066, 1333 | 1066 1333 1600 | n/a | 800, 1066
SRx4 | 2GB | 4GB | 8GB | 1066 1333 | 1066 1333 1600 | 1066 1333 | 1066 1333 1600 | 1066, 1333 | 1066 1333 1600 | 1066, 1333 | 1066 1333 1600 | n/a | 800, 1066
DRx4 | 4GB | 8GB | 16GB | 1066 1333 | 1066 1333 1600 | 1066 1333 | 1066 1333 1600 | 1066, 1333 | 1066 1333 1600 | 1066, 1333 | 1066 1333 1600 | n/a | 800, 1066
QRx4 | 8GB | 16GB | 32GB | 800 | 1066 | 800 | 800 | 800 | 1066 | 800 | 800 | n/a | n/a
QRx8 | 4GB | 8GB | 16GB | 800 | 1066 | 800 | 800 | 800 | 1066 | 800 | 800 | n/a | n/a

Table 4. LRDIMM Support Guidelines

Ranks Per DIMM & Data Width¹ | Memory Capacity Per DIMM² | Speed (MT/s) and Voltage Validated by Slot per Channel (SPC) and DIMM Per Channel (DPC)³,4,5
2 Slots per Channel Intel® Sever Board S2600GL | 3 Slots per Channel Intel® Sever Board S2600GZ
1DPC and 2DPC | 1DPC and 2DPC | 3DPC
1.35V | 1.5V | 1.35V | 1.5V | 1.35V | 1.5V
(DDP)⁶ QRx4 | 16GB | 32GB | 1066 | 1066, 1333 | 1066 | 1066, 1333 | 1066 | 1066
QRx8 (P)⁶ | 8GB | 16GB | 1066 | 1066, 1333 | 1066 | 1066 | 1066 | 1066

### 3.3 Riser Card Support

The server board shall provide two riser cards, and the riser card slots can be configured to meet a range of usage models. Exact PCIe* lane assignments to the slots is determined by the board vendor.

The following section shows examples of 1U and 2U riser cards:

- 1U – One add-in card slot – PCIe* x16, x16 mechanical


- | 2U – Three add-in card slots – | Slot # | Description
Slot-1 (Top) | PCIe* x8, x16 mechanical
Slot-2 (Middle) | PCIe* x8, x16 mechanical
Slot-3 (Bottom) | PCIe* x8, x8 mechanical



10 | Confidential | Revision 0.5
- 2U – Two add-in card slots –
- 2U – Three add-in card slots –

### 3.4 Network Interface

Each Ethernet port shall drive two LEDs located on each network interface connector. The LED at the right of the connector is the link/activity LED and indicates network connection when on, and transmit/receive activity when blinking. The LED at the left of the connector indicates link speed as defined in the following table.

Table 5. External RJ45 NIC Port LED Definition

LED | Color | LED State | NIC State
Left | Green | Off | LAN link not established
| | On | LAN link is established
| | Blinking | LAN activity is occurring
Right | | Off | 10 Mb/sec data rate
| Green | On | 100 Mb/sec data rate
| Yellow | On | 1000 Mb /sec data rate
Slot # | Description
Slot-1 (Top) | PCIe* x16, x16 mechanical
Slot-2 (Bottom) | PCIe* x8, x8 mechanical
Slot # | Description
Slot-1 (Top) | PCIx 133MHz
Slot-2 (Middle) | PCIx 133 MHz
Slot-3 (Bottom) | PCIe* x8, x8 mechanical

### 3.5 I/O Module Support

To broaden the standard on-board feature set, the server board may provide support for additional I/O Module options. The I/O module shall attach to a vendor defined connector supporting x8 PCIe* Gen3 signals from the CPU 1 processor.

12 | Confidential | Revision 0.5

## 4. Technology Support

### 4.1 Intel® Trusted Execution Technology

The Intel® Xeon® Processor E5 2600 Product Family supports Intel® Trusted Execution Technology (Intel® TXT), which is a robust security environment designed to help protect against software-based attacks. Intel® Trusted Execution Technology integrates new security features and capabilities into the processor, chipset and other platform components. When used in conjunction with Intel® Virtualization Technology and Intel® VT for Directed IO, with an active TPM, Intel® Trusted Execution Technology provides hardware-rooted trust for your virtual applications.

### 4.2 Intel® Virtualization Technology – Intel® VT-x/VT-d/VT-c

Intel® Virtualization Technology consists of three components which are integrated and interrelated, but which address different areas of Virtualization.
- Intel® Virtualization Technology (VT-x) is processor-related and provides capabilities needed to provide a hardware assist to a Virtual Machine Monitor (VMM).
- Intel® Virtualization Technology for Directed I/O (VT-d) is primarily concerned with virtualizing I/O efficiently in a VMM environment. This would generally be a chipset I/O feature, but in the Second Generation Intel® Core™ Processor Family there is an Integrated I/O unit embedded in the processor, and the IIO is also enabled for VT-d.
- Intel® Virtualization Technology for Connectivity (VT-c) is primarily concerned I/O hardware assist features, complementary to but independent of VT-d.

### 4.3 Trusted Platform Module (TPM) Support

The server board shall support TPM 1.2.

## 5. Platform Management Functional Overview

This section describes the management features supported by the server board.

### 5.1 Management Controller Firmware Feature Support

The following sections outline features that the integrated management controller firmware can support. Support and utilization for some features is dependent on the server platform in which the server board is integrated and any additional system level components and options that may be installed.

### 5.1.1 IPMI Features

- IPMI 2.0 Features Shall support OCP remote management
- May support Baseboard management controller (BMC)
- Shall support IPMI Watchdog timer
- Shall support Chassis device functionality, including power/reset control and BIOS boot flags support
- Shall support Field Replaceable Unit (FRU) inventory device functionality
- Shall support System Event Log (SEL) device functionality Shall support Sensor Data Record (SDR) repository device functionality
- Shall support Sensor device and sensor scanning/monitoring Shall support Serial-over-LAN (SOL)

14 | Confidential | Revision 0.5

### 5.1.2 Non IPMI Features

The management controller supports the following non-IPMI features.

- Shall support In-circuit management firmware update
- Shall support Chassis intrusion detection
- Shall support Fan speed control
- Shall support Fan redundancy monitoring and support
- Shall support Hot-swap fans
- Shall support Power Supply Fan Sensors
- May support System Airflow Monitoring
- Shall support Exit Air Temperature Monitoring
- May support Ethernet Controller Thermal Monitoring
- Shall support Platform environment control interface (PECI) thermal management support
- Shall support DIMM temperature monitoring
- Shall support Power supply redundancy monitoring and support
- May support power management (e.g. power capping at node level)
- May support diagnostic beep codes for fault conditions.
- Shall support System status LED and chassis ID LED.
- May support secure lockout of certain front panel functionality
- Shall support Power state retention
- May support Integrated KVM
- Shall support DCMI 1.1 compliance (product-specific).
- May support management of PMBus rev1.2 compliant power supplies
- May support Smart Ride Through (SmaRT) / Closed Loop System Throttling (CLST)
- Shall support Power Supply FW Update
- May support Power Supply Compatibility Check

### 5.2 Remote BIOS Update

The BIOS can be updated remotely under these scenarios:
- Scenario 1: Sample/Audit BIOS settings
- Return current BIOS settings, or
- Save/export BIOS settings in a human-readable form that can be restored/imported (as in scenario 2)
- Scenario 2: Update BIOS with pre-configured set of BIOS settings
- Update/change multiple BIOS settings
- Reboot
- Scenario 3: BIOS/firmware update with a new revision
- Load new BIOS/firmware on machine and update, retaining current BIOS settings
- Reboot

Additionally, the update tools have the following capabilities:
- Update from the operating system over the LAN – the OS standard is CentOS v5.2
- Can complete BIOS update or setup change with a single reboot (no PXE boot, no multiple reboots)
- No user interaction (like prompts)
- BIOS updates and option changes do not take longer than five minutes to complete

- Can be scripted and propagated to multiple machines
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

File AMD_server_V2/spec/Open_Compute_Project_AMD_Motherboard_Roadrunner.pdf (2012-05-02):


# AMD Motherboard

# Hardware v3.0

Authors: Bob Ogrey, Eugene Chung, Otto Joe

### 2 April 15, 2012

### 1 Scope

This document defines the technical specifications for the general purpose AMD motherboard that will be used in financial services Open Compute Project servers.

2 Contents

Open Compute Project AMD Motherboard Hardware v3.0

http://opencompute.org | 3

### 4 April 15, 2012
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

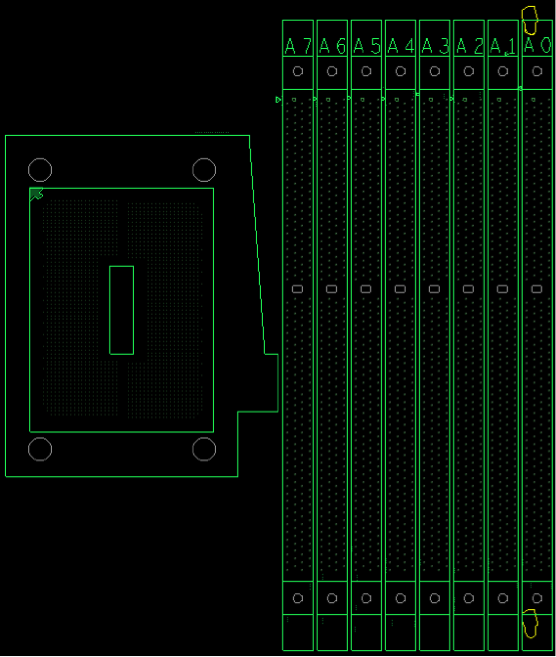
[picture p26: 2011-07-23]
AMD_server_V2/images/amd_dimm_silkscreen.png

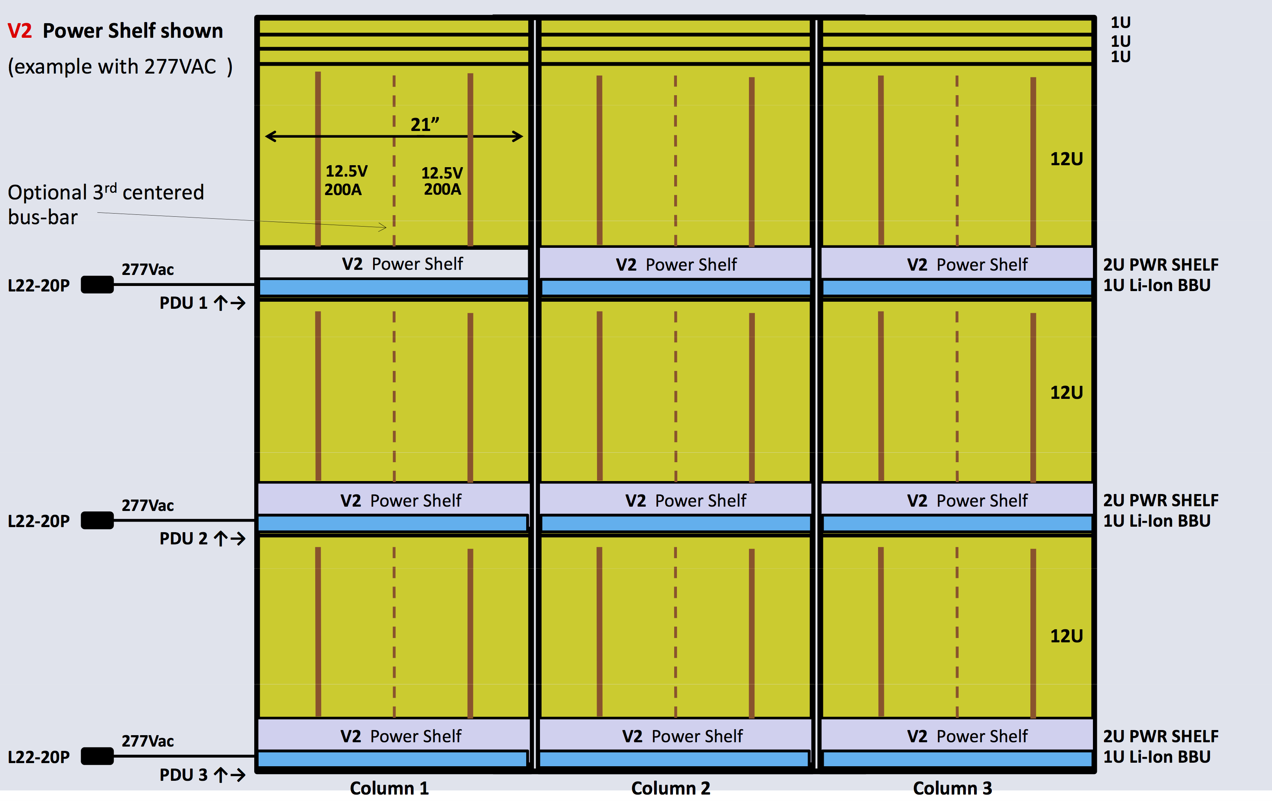
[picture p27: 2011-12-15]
open_rack/images/v2_power_shelf.png

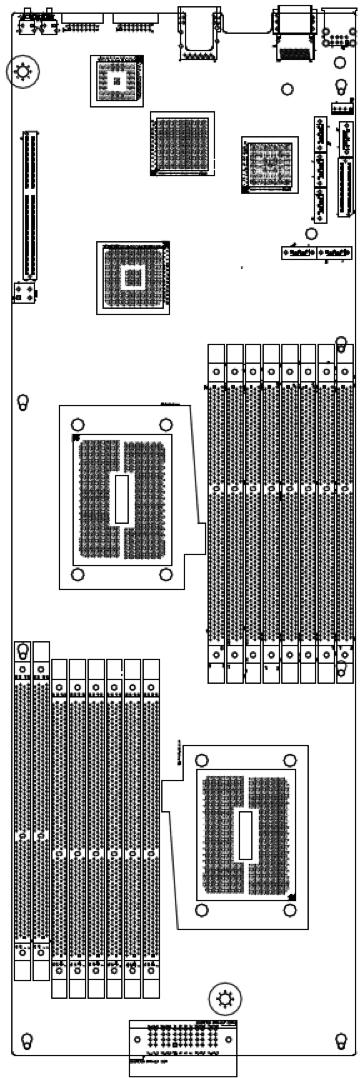
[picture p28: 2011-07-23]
AMD_server_V2/images/amd_placement.png

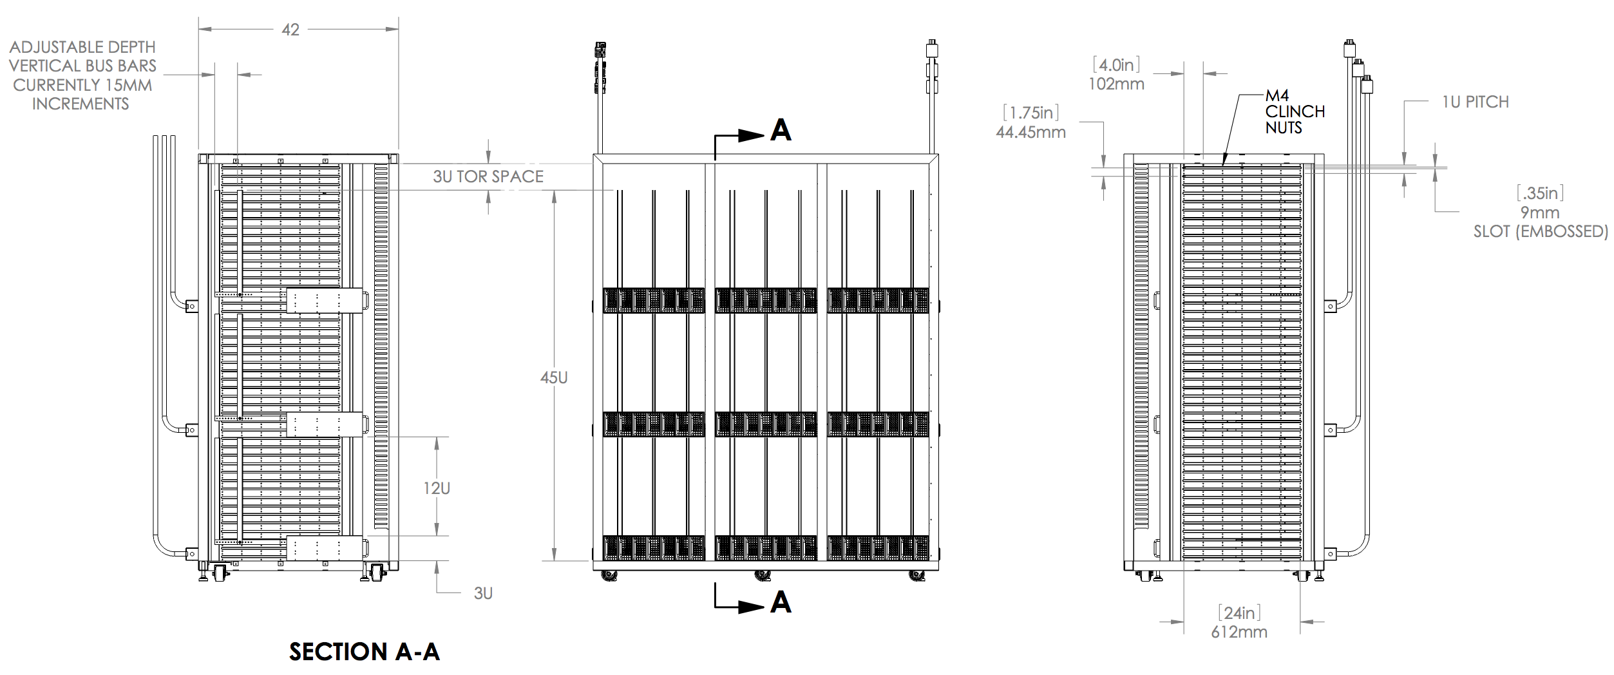
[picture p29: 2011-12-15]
open_rack/images/triplet_control_drawing_hpdu.png

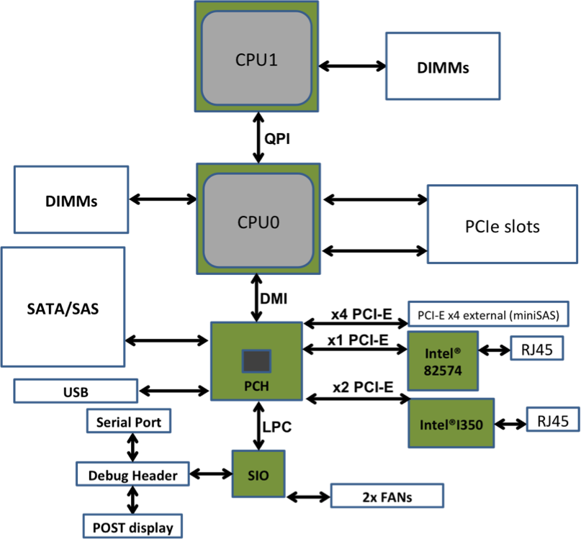
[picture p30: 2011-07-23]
Intel_server_V2/images/intel_en_block.png

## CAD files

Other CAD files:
open_rack/spec/03-000200 REV 01 PDU AC OPEN RACK.STEP

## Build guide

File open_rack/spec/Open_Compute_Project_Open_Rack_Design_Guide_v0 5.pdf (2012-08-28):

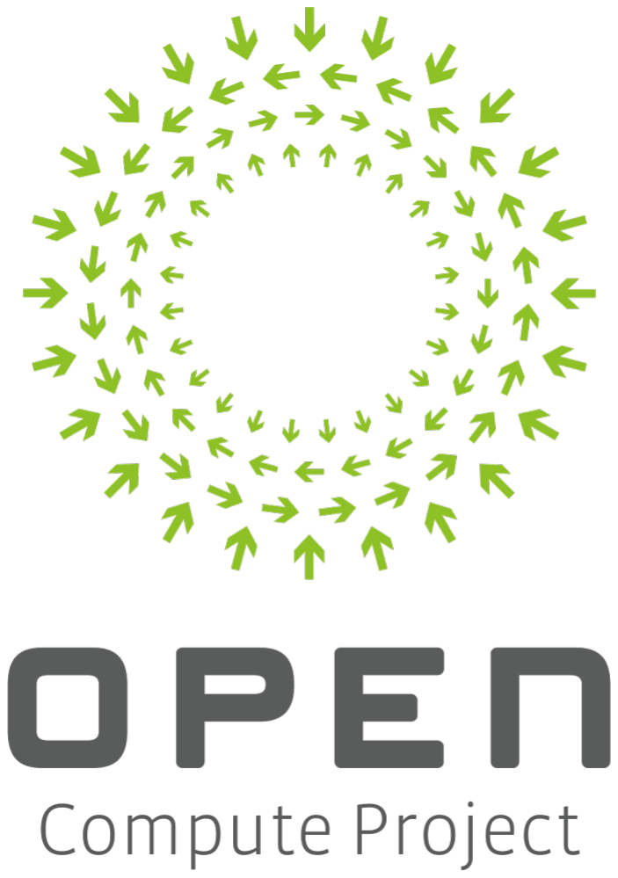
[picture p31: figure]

# Open Rack Design Guide v0.5

Draft: August 24, 2012
Author: Steve Mills

### 2 August 24, 2012

## 1 Contents

2.2 Reference
3 Overview

of

Facebook's

Open

Rack
3.1 Open

Rack

Design
4 Reference

Chassis
5 Contact

Information

for

Chassis

Enabled
5.1 Bus

Bar

Power

Open Compute Project Open Rack Design Guide v0.5

http://opencompute.org | 3
2 | Introduction
2.1 | Goal This design guide provides the engineering details required for IT equipment suppliers to build systems compatible with the Open Rack platform. The Open Rack is focused on fulfilling the Open Compute Project goal of maximizing operational efficiency of large scale deployments by adhering to the following the principles: • Installation and service operations are located in the cold aisle • Data cables are located on the front of the rack to improve technician access • Component faults are identifiable from the front • Routine service does not require the use of tools • Non-recyclable components are minimized • Designs are vanity free • Racks are integrated directly into the data center air containment solutions
2.2 | Reference Documents The following specification is available on the OCP website: • Open Rack specification (opencompute.org/projects/open-rack/)

## 3 Overview of Facebook's Open Rack Implementation

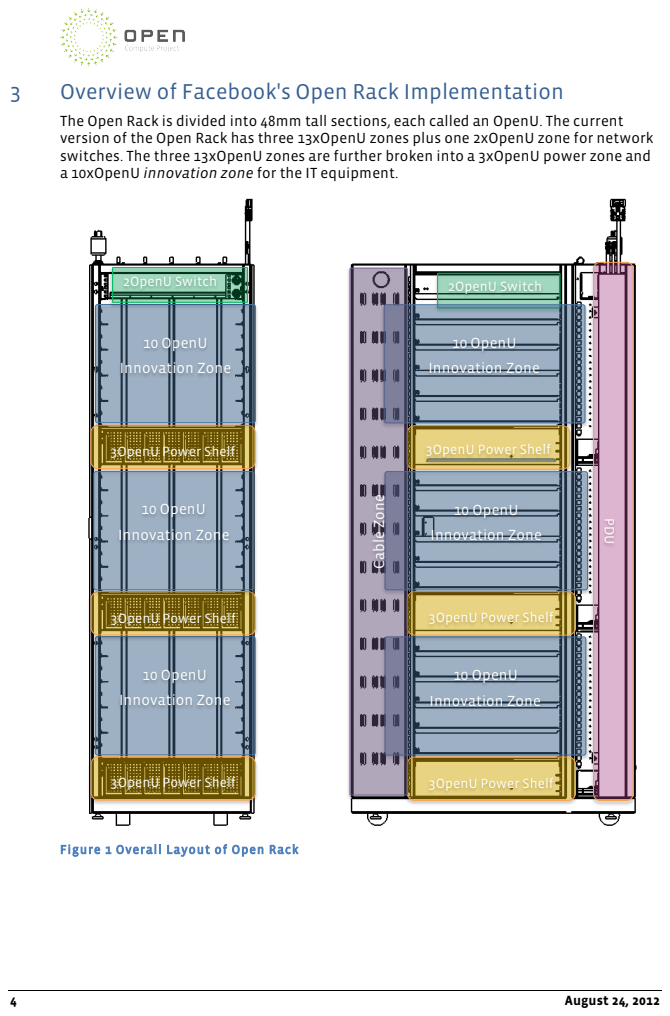
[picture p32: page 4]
4 August 24, 2012; 3OpenU Power Shelf; 10 OpenU; Innovation Zone; 2OpenU Switch; PDU; Cable Zone

The Open Rack is divided into 48mm tall sections, each called an OpenU. The current
version of the Open Rack has three 13xOpenU zones plus one 2xOpenU zone for network
switches. The three 13xOpenU zones are further broken into a 3xOpenU power zone and
a 10xOpenU innovation zone for the IT equipment.

Figure 1 Overall Layout of Open Rack

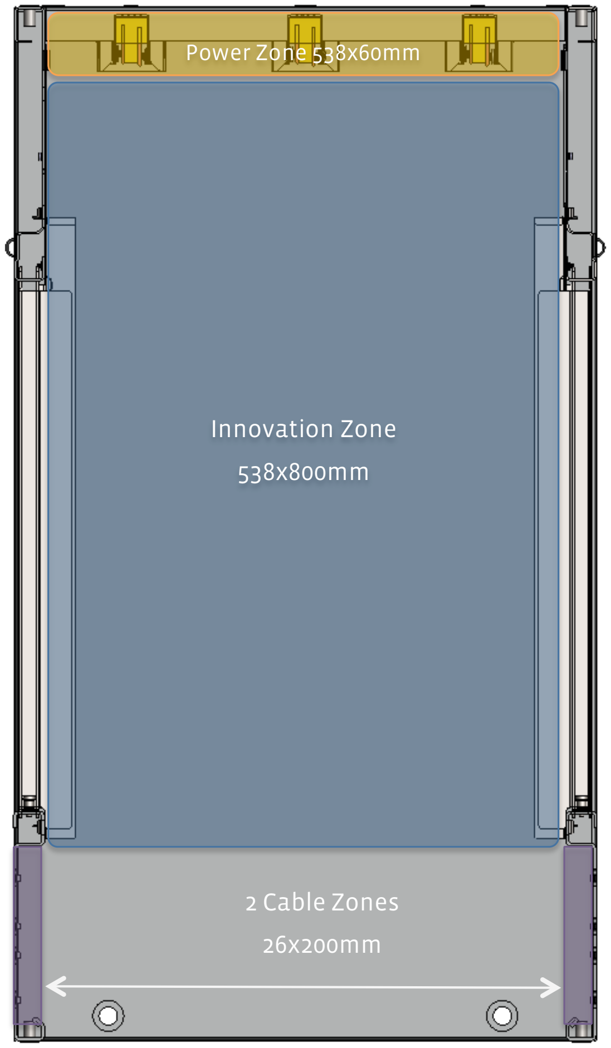
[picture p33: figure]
Power Zone 538x60mm; Innovation Zone; 2 Cable Zones

http://opencompute.org | 5

Figure 2 Top View of the Open Rack
The power zone receives power provided by the data center into an AC and a DC PDU. The PDUs distribute the power to each of the 3OpenU power shelves. The power shelves consist of 7 hot-swap power supplies that are serviceable from the cold aisle. The power exits the power shelf and is distributed along three 12V bus bars to the Innovation zone above.

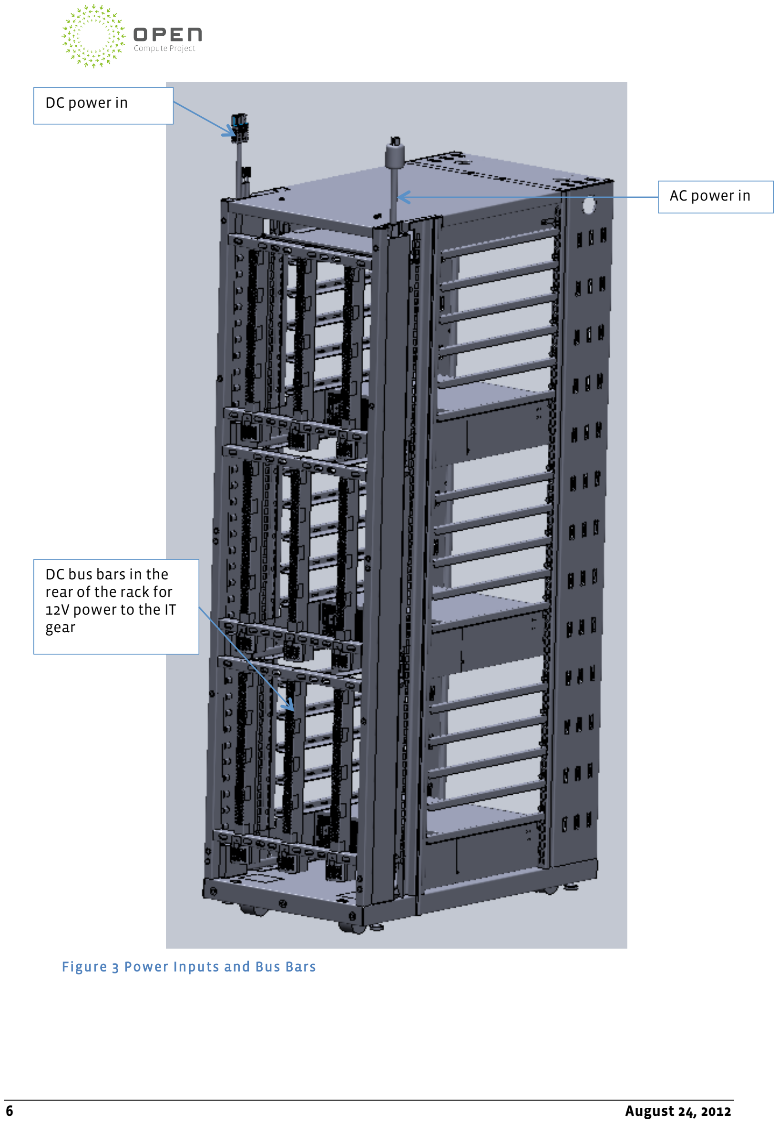
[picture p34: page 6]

### 6 August 24, 2012

Figure 3 Power Inputs and Bus Bars

DC bus bars in the
rear of the rack for
12V power to the IT
gear

DC power in

AC power in

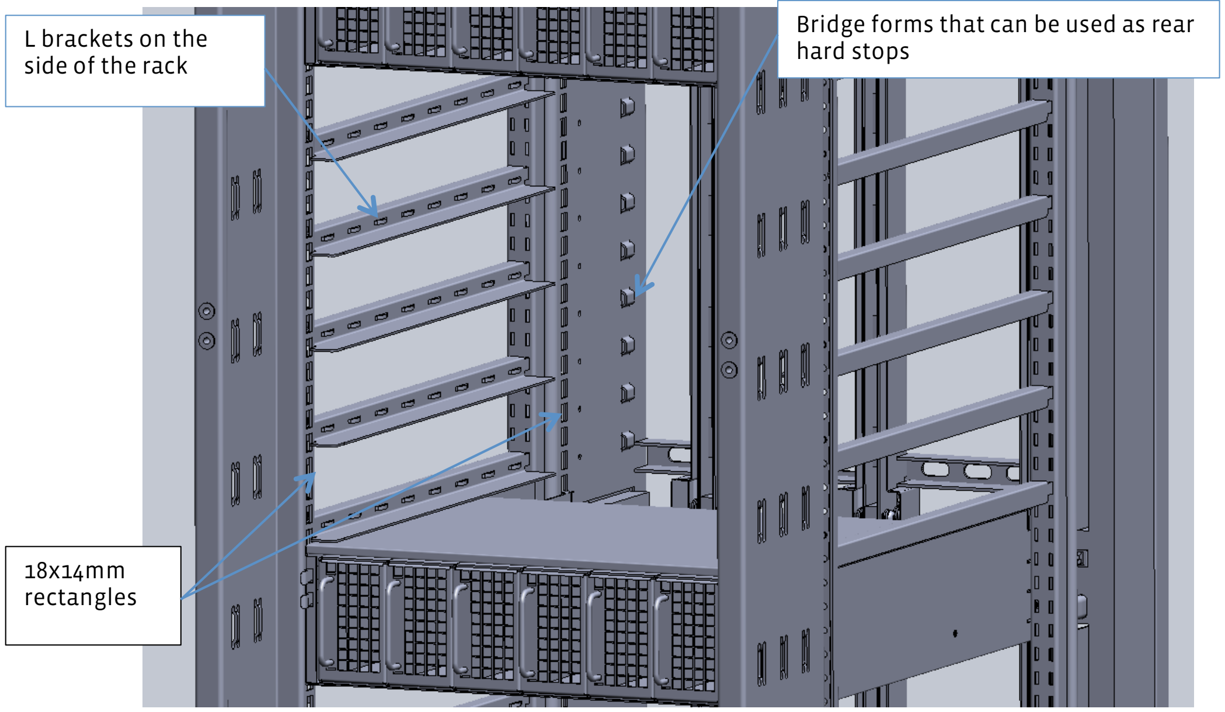
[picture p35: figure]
L brackets on the side of the rack; 18x14mm rectangles; Bridge forms that can be used as rear hard stops

http://opencompute.org | 7

The innovation zone is an area available to IT equipment suppliers. Due to the power bus bar in the back, the IT equipment is easy to install and service from the cold aisle. A simple set of brackets extends from the sides of the rack to provide a shelf for the gear to sit on when it is installed in the rack.
The cable zones are located in the front of the rack to so that technicians can service the cables without having to enter the hot aisle. The cables are recessed into protected areas on the sides of the racks so that the IT gear will not damage the cables when it is added or removed.
Please consult the Open Rack hardware specification for a more complete definition of all Open Rack components.
3.1 Open Rack Design Details The equipment is supported on L-shaped brackets that snap into the sides of the rack. These brackets can be populated in any ½OpenU (24mm) location in order to support IT equipment of different heights. This adjustability allows a single rack to support different types of equipment over many generations.

Figure 4 Detail of Knife Brackets
There is a series of 18x14mm rectangles that repeat in a 24mm pattern along both front and back vertical rails. These slots can be used to latch systems into the rack or to hang adapter brackets that can be customized to support different types of equipment.
A bridge form in the back of the rack at every OpenU can be used as a stopping surface to prevent rearward motion of the IT equipment in the rack.

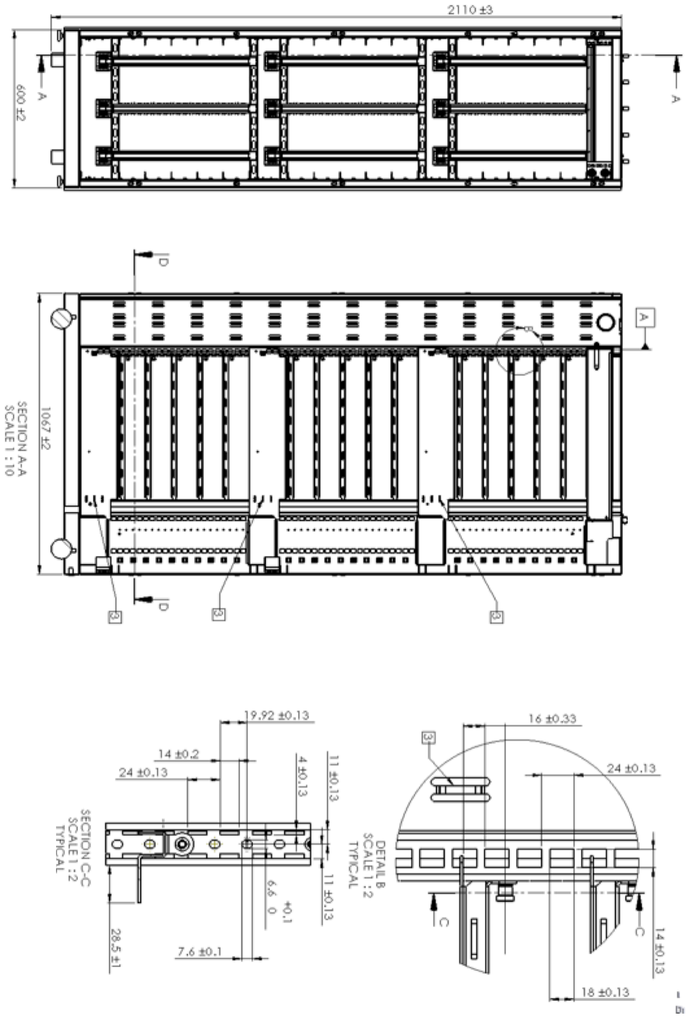
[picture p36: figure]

### 8 August 24, 2012

Figure 5 Open Rack Cabinet, Detailing How the Knife and L Brackets Attach

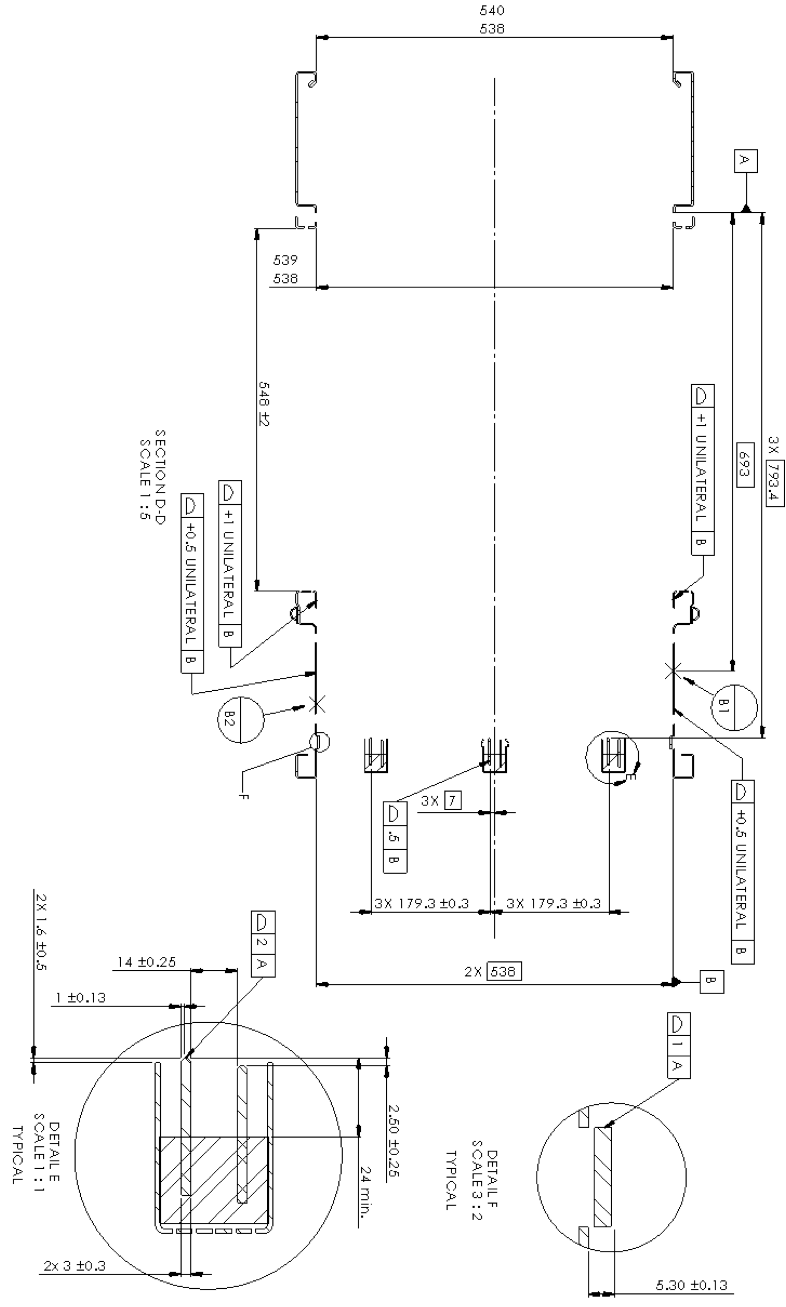
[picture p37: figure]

http://opencompute.org | 9

Figure 6 Top View Cross Section of the Open Rack Showing Bus Bars and Rack Openings

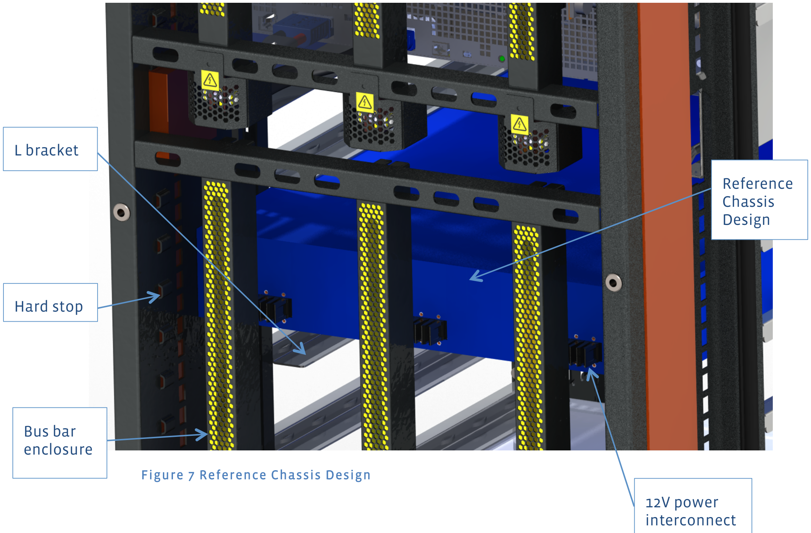
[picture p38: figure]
Figure 7 Reference Chassis Design; Hard stop; Bus bar enclosure; 12V power interconnect; L bracket; Reference Chassis Design

### 10 August 24, 2012

4 Reference Chassis Design The reference design uses latches that snap into the rectangular holes in the front of the rack. The latches provide a stop to prevent forward motion of the IT equipment in the rack. This is just one example of how the rectangles might be used. The chassis could also have cams that use the rectangles to push against the rack to make sure that the chassis is always forced against the hard stop in the back of the rack. The 12V bus bar connector location is controlled to make sure that it will contact the bus bar since it is a blind-mate connection. The reference design assumes that the 12V bus bar clip referenced in section 5.1 is included in the design. Any equipment that uses a different clip or method of attaching to the bus bar is free to deviate from the specification as the designer accepts the responsibility of ensuring that the equipment always mates with the bus bar and the rack. The chassis height must be a minimum of 1xOpenU tall, but can grow in height by ½xOpenU increments of 24mm. The chassis height should be no greater than (24mm * OpenU) -2.5mm. The 2.5mm provides room for the L bracket that the chassis rests on and clearance in the rack to make sure that it does not rub the L bracket above.

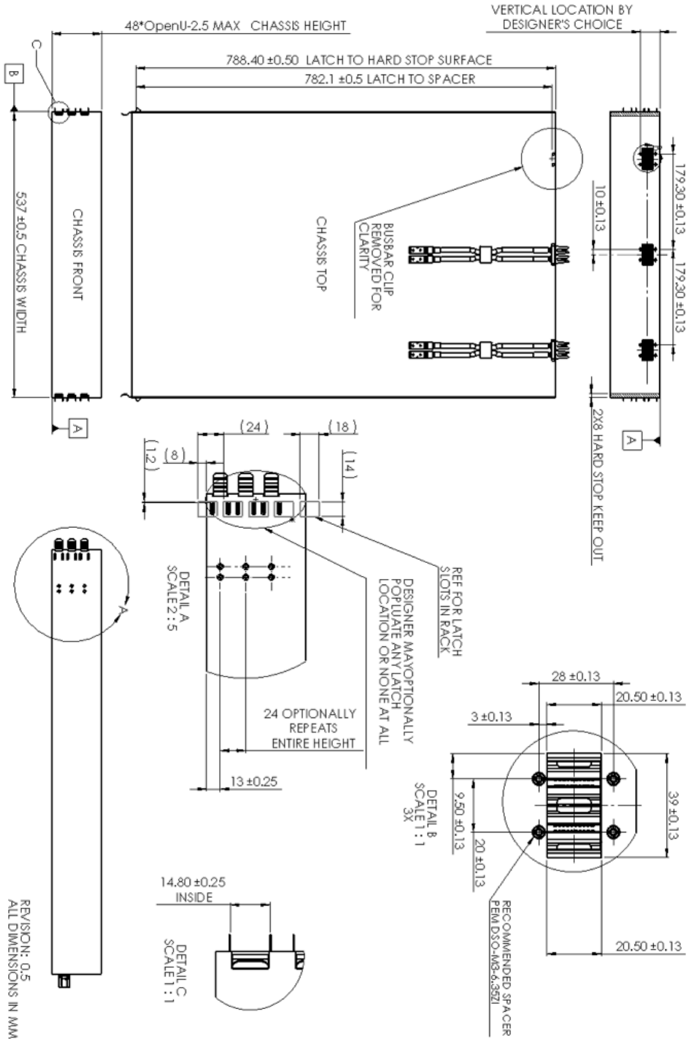
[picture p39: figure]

http://opencompute.org | 11

Figure 8 Reference Chassis Design for 12V DC Connector

### 12 August 24, 2012

5 | Contact Information for Chassis Enabled Components
5.1 | Bus Bar Power Interconnect

5.1.1 Methode Electronics

Vic Geevarghese | Ty Underwood
Field Application Engineering Manager | Field Application Engineer
Business Phone: 847-222-2563 | Business Phone: 408-453-4823
Mobile Phone: 312-912-2873 | Mobile Phone: 925-785-4456
vgeevarghese@methode.com | ty@methode.com

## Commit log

2011-07-23 Initial addition of multimarkdown versions of the AMD and Intel motherboards, and a script to make a zip file for web distribution of our CAD files
2012-05-08 create summit-specific directory for content
    this directory will contain the presentations and other material from
    the summit in San Antonio in May 2012.
2012-05-09 add the remaining v1 OCP specs
    create an archive for the original motherboard and chassis/triplet rack
    specs; create directories for the other v1 specs that are still active
    (battery cabinet, PSU, data center design).
2012-05-09 virtual IO summit material
    Adding James Hesketh's content from the OCP Summit.
2012-05-25 DC design presentation and 700W power supply spec
    The data center design presentation is an update from the one presented
    at the New York OCP summit from October 2011. The power supply spec
    discusses both the 700W and 450W versions.
2012-08-28 Open Rack design guide
    Adding the current version of the Open Rack design guide, which is
    aimed at IT equipment suppliers who want to build systems compatible
    with the Open Rack.
2012-09-10 Update AMD and Intel CAD files
    There was an error (blob too big) with the original versions of these
    files. Uploading again with different names to see if these work.
2012-09-18 Open Rack updates
    * Open Rack 1.0 specification with its mechanical files ("06-000050
    REV01 SINGLET RACK")
    * Open Rack 0.6 (triplet) spec with the mechanical files ("27-000019 -
    STRUCTURE OPEN RACK TRIPLET")
    * PDU mechanical files ("03-000200 REV 01 PDU AC OPEN RACK.STEP")
    [03-000200 REV 01 PDU AC OPEN RACK.STEP]
2012-09-18 Update files
    One more time, without spaces in file names. Also, compress STEP file
    so it can be downloaded.
    [03-000200 REV 01 PDU AC OPEN RACK.STEP]
2012-09-27 virtual IO charter
    current draft of the Virtual IO charter document.
2012-09-27 Virtual IO charter, udpated Open Rack CAD file
    current draft of the virtual IO charter. Updated Open Rack 1.0 STEP
    file in RAR form, to replace the corrupt earlier version (sorry
    everyone!).
